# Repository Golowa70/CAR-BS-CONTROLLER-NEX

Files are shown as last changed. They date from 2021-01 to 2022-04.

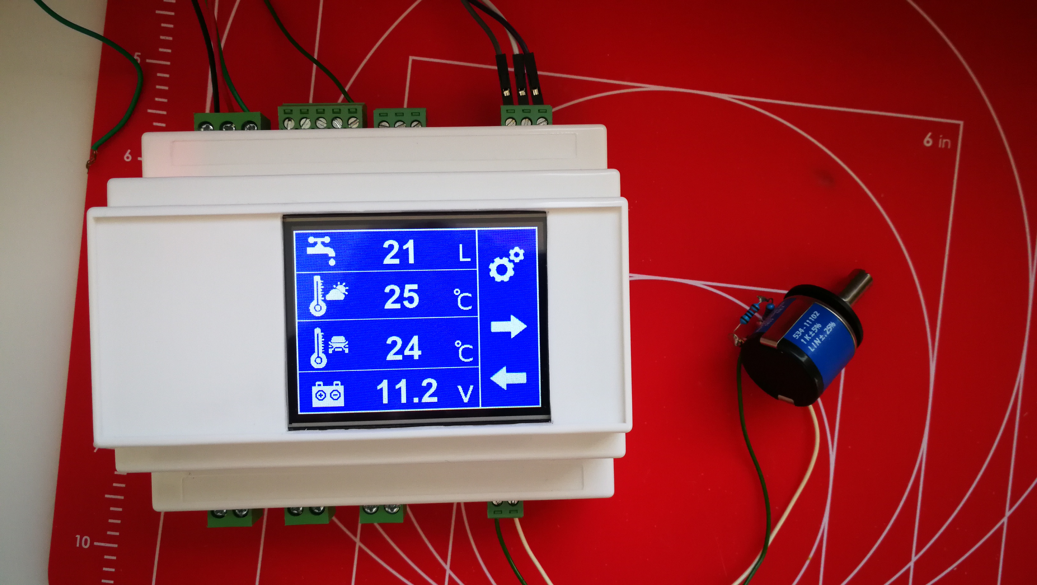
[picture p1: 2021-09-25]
Photo/IMG_20210619_180537.jpg

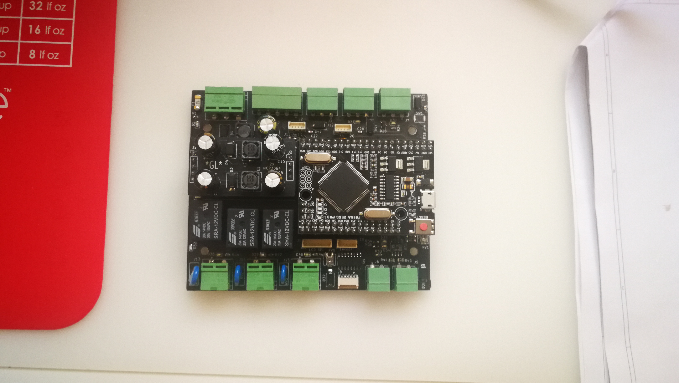
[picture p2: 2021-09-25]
Photo/IMG_20210616_192407.jpg

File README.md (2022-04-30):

# CAR-BS-CONTROLLER-NEX

Контроллер для дополнительного оборудования автомобиля на базе ардуино Mega  c сенсорным экраном Nextion. В качестве дополнительного оборудования установлен преобразователь напряжения 12/220в(1500ватт), холодильник, бак с водой (включая эл.насос, датчик количества воды и датчик приближения для активации насоса ). 

На данный момент реализованы следующие функции: 

- Автоматическое отключение преобразователя напряжения как по напряжению так и по времени.

- Управление водяным насосом для мойки рук с помощью датчика приближения и индикация количества воды в баке.

- Звуковое оповещение низкого уровня воды в баке.

- Индикация  количества воды, наружной и внутренней температуры, напряжения аккумулятора. 

- Передача данных на головное устройство (Андроид магнитола) по протоколу ModBus.

- Таймер на полное отключение контроллера.

- Диагностика питания сенсоров, шины 1wire, шины Pjon swbb

На данный момент контроллер установлен в автомобиле Hyundai I800 и успешно используется.

Прошивка контроллера  по прежнему находится в стадии разработки и тестирования.

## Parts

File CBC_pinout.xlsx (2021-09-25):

Pin | Direction | Function | Description | Столбец5
D2 | OUT | BUZZER | выход ШИМ на пассивную пищалку для звуковой индикации
D3 | IN/OUT | PJON BUS | выход интерфейса PJON
D4 | IN/OUT | 1WIRE BUS | выход интерфейса 1WIRE
D5 | IN | WATER FLOW SENSOR | вход датчика (счетчика) протечки
D6 | OUT | RS485DE | выход управления направлением (приём/передача) RS485
D7 | OUT | 5V SENSORS ENABLE | выход управления питанием сенсоров +5в
D8 | OUT | ADM705 RESET | выход для сброса таймера ADM705
D9 | OUT | MAIN SUPPLY ENABLE | выход управления основным питанием 7.2в
D10 | IN | ONBOARD BUTTON | кнопка на плате
D13 | OUT | STATUS LED | светодиод состояния системы
D16 | UART2 TX | RS485 TX
D17 | UART2 RX | RS485 RX
D18 | UART1 TX | *LCD NEXTION TX | разъём J11
D19 | UART1 RX | *LCD NEXTION RX | разъём J11
D20 | I2C SDA | * | разъём J12
D21 | I2C SCL | * | разъём J12
D22 | OUT | WATER PUMP OUT | выход управления реле водяного насоса
D23 | OUT | LIGHT OUT | выход управления светом
D24 | OUT | CONVERTER OUT | выход управления конвертером 12/220
D31 | OUT | SPARE OUT 1 | резервный выход 1 разъём J8
D32 | OUT | SPARE OUT 2 | резервный выход 2 разъём J8
D33 | OUT | SPARE OUT 3 | резервный выход 3 разъём J8
D34 | OUT | SPARE OUT 4 | резервный выход 4 разъём J8
D35 | IN | ENCODER SW | вход энкодера (кнопка) разъём J10
D36 | IN | ENCODER DT | вход энкодера (данные) разъём J10
D37 | IN | ENCODER CLK | вход энкодера (сигнал синхронизации) разъём J10
D41 | IN | POWER OK FROM ADM705 | вход от компаратора входного напряжения
D42 | IN | SPARE INPUT 1 | резервный вход
D43 | OUT | LCD RST | выход сброса экрана разъём J9 | ST7920
D44 | OUT | LCD BLA | выход управления подсветкой экрана разъём J9
D51 |  | LCD RW (SPI MOSI) | аппаратный SPI линия данных разъём J9
D52 |  | LCD E (SPI CLK) | аппаратный SPI линия синхронизации разъём J9
D53 |  | LCD DI (SPI CS) | аппаратный SPI линия выбора слэйва разъём J9
A0 | IN | DOOR SWITCH
A1 | IN | PROXIMITY SENSOR/BUTTON
A2 | IN | IGNITION SWITCH
A3 | IN | WASHER WATER LEVEL
A4 | IN | SUPPLY VOLTAGE
A5 | IN | SENSORS VOLTAGE
A6 | IN | RESESTIVE SENSOR | 0-190 OHM

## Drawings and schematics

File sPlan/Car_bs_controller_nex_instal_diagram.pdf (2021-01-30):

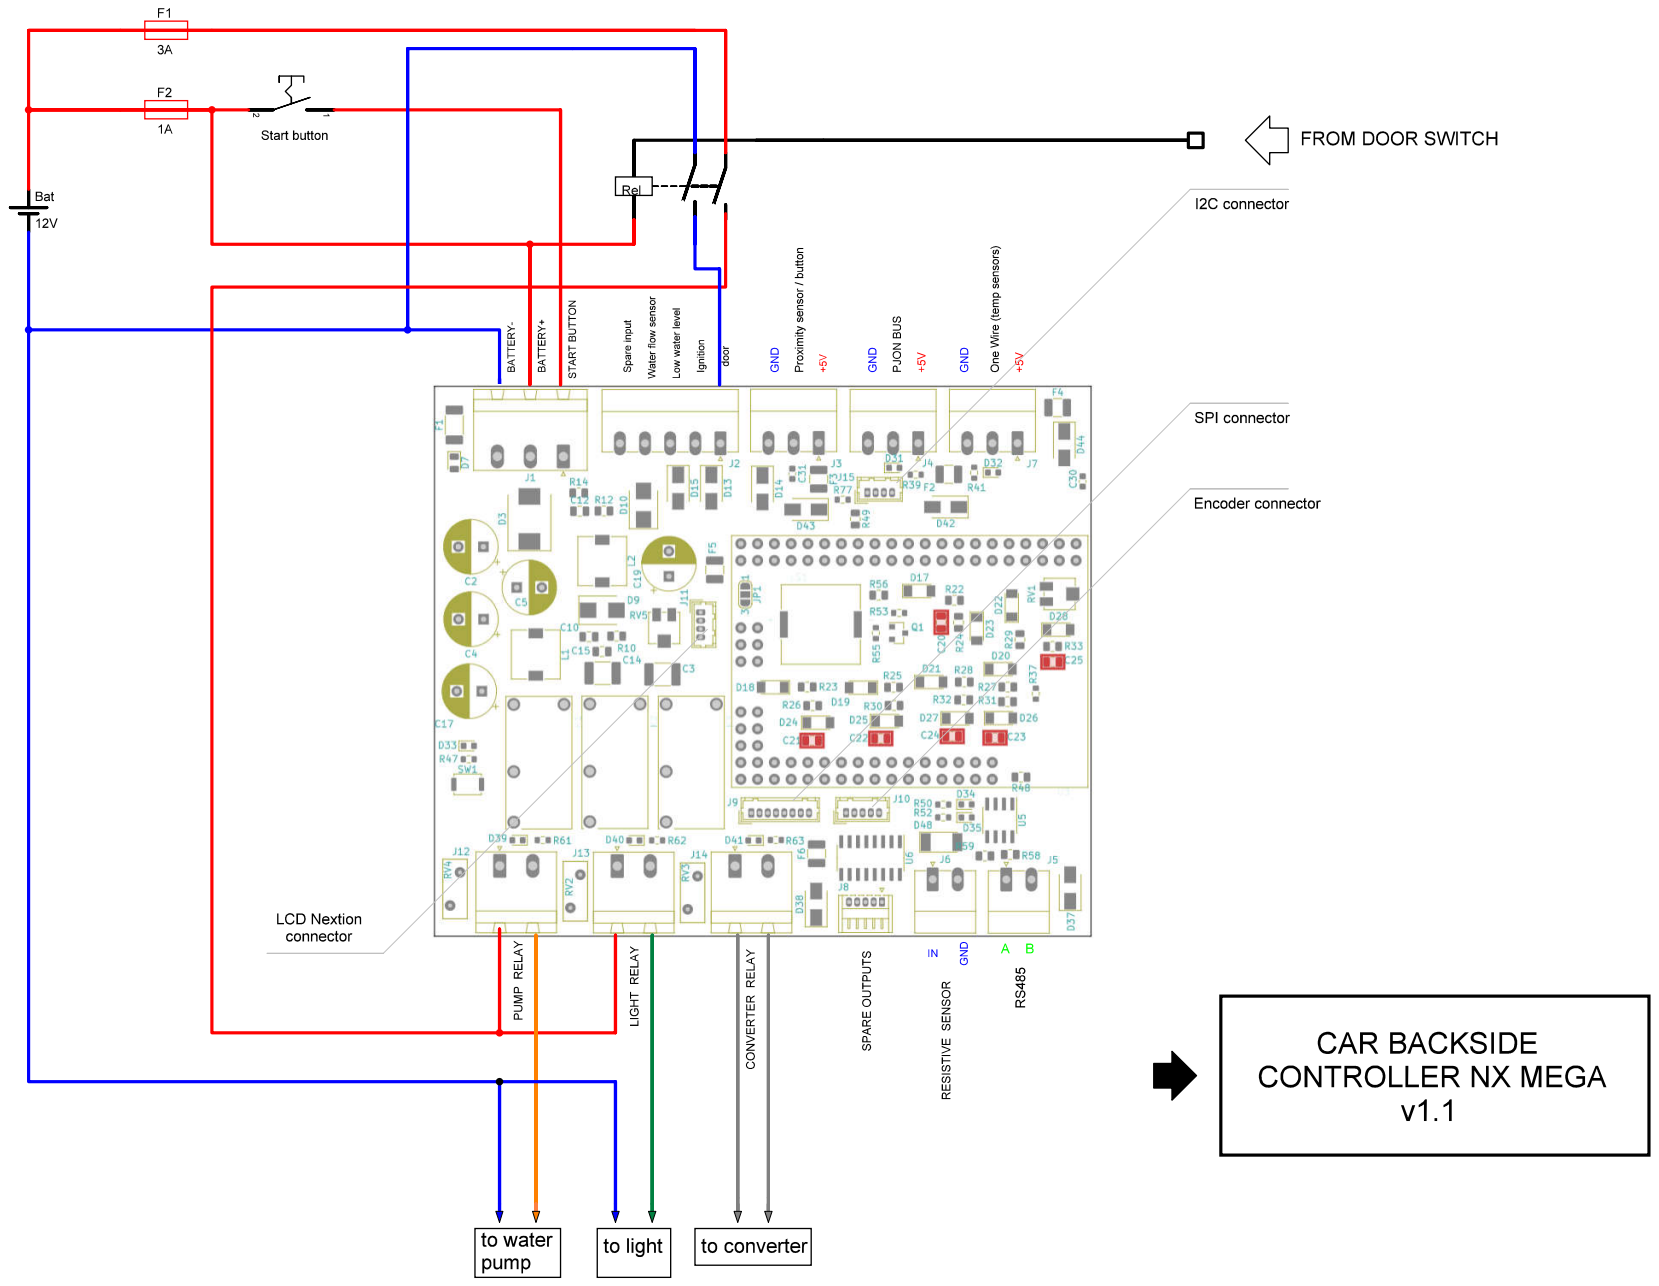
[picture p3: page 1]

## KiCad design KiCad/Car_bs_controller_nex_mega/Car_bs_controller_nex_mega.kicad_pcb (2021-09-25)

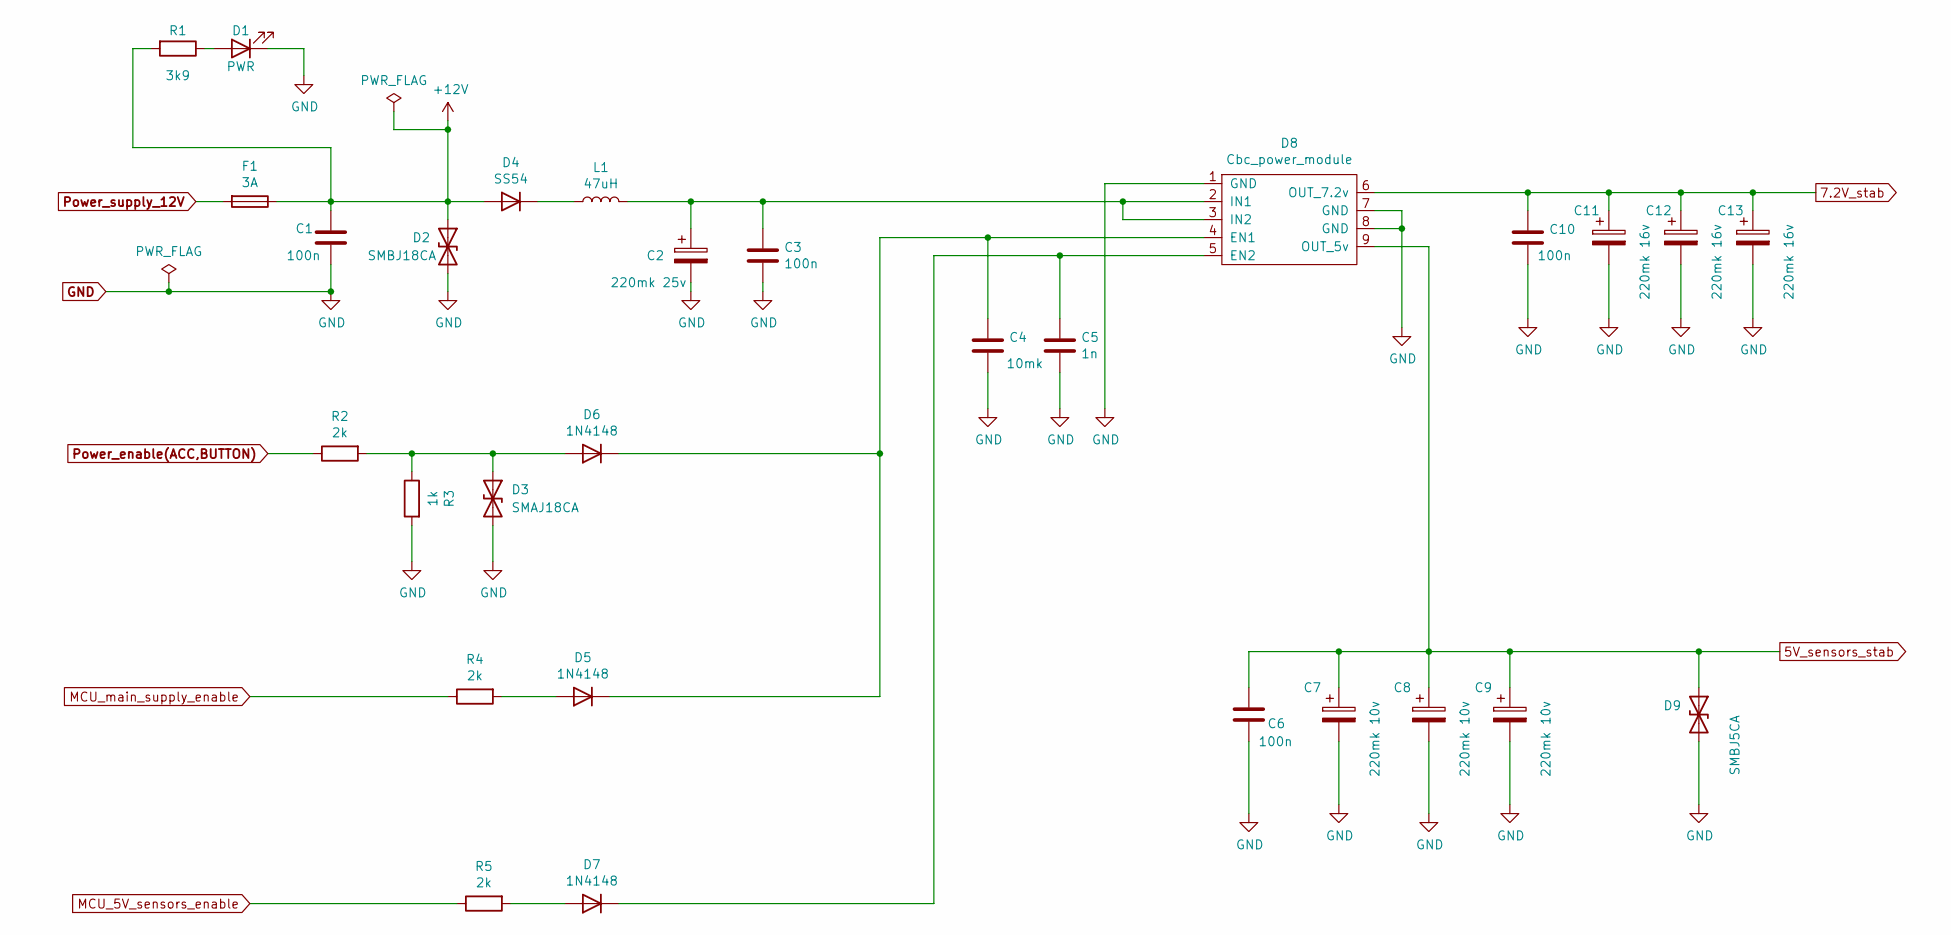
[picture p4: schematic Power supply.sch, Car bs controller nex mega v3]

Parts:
C1, C3, C6, C10: 100n; C_0805_2012Metric
C2: 220mk 25v; CP_Radial_D8.0mm_P3.80mm
C4: 10mk; C_1210_3225Metric_Pad1.33x2.70mm_HandSolder
C5: 1n; C_0805_2012Metric
C7, C8, C9: 220mk 10v; CP_Radial_D6.3mm_P2.50mm
C11, C12, C13: 220mk 16v; CP_Radial_D6.3mm_P2.50mm
D1: PWR; LED_0805_2012Metric
D2: SMBJ18CA; D_SMB
D3: SMAJ18CA; D_SMA
D4: SS54; D_SMB
D5, D6, D7: 1N4148; D_MiniMELF
D8: Cbc_power_module
D9: SMBJ5CA; D_SMA
F1: 3A; Fuse_2010_5025Metric
L1: 47uH; L_7.3x7.3_H4.5
R1: 3k9; R_0603_1608Metric_Pad0.98x0.95mm_HandSolder
R2, R4, R5: 2k; R_0603_1608Metric_Pad0.98x0.95mm_HandSolder
R3: 1k; R_0603_1608Metric_Pad0.98x0.95mm_HandSolder

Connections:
5V_sensors_stab: C6.1, C7.1, C8.1, C9.1, D8.9 (OUT_5v), D9.1 (A1); also elsewhere on the board
7.2V_stab: C10.1, C11.1, C12.1, C13.1, D8.6 (OUT_7.2v); also elsewhere on the board
+12V: C1.1, D2.1 (A1), D4.2 (A), F1.1, R1.2; also elsewhere on the board
GND: C1.2, C2.2, C3.2, C4.2, C5.2, C6.2, C7.2, C8.2, C9.2, C10.2, C11.2, C12.2, C13.2, D1.1 (K), D2.2 (A2), D3.2 (A2), D8.1 (GND), D8.7 (GND), D8.8 (GND), D9.2 (A2), R3.2; also elsewhere on the board
MCU_5V_sensors_enable: R5.1; also elsewhere on the board
MCU_main_supply_enable: R4.1; also elsewhere on the board
unnamed: C2.1, C3.1, D8.2 (IN1), D8.3 (IN2), L1.2
unnamed: C4.1, D5.1 (K), D6.1 (K), D8.4 (EN1)
unnamed: C5.1, D7.1 (K), D8.5 (EN2)
unnamed: D1.2 (A), R1.1
unnamed: D3.1 (A1), D6.2 (A), R2.2, R3.1
unnamed: D4.1 (K), L1.1
unnamed: D5.2 (A), R4.2
unnamed: D7.2 (A), R5.2
Power_enable(ACC,BUTTON): R2.1; also elsewhere on the board
Power_supply_12V: F1.2; also elsewhere on the board

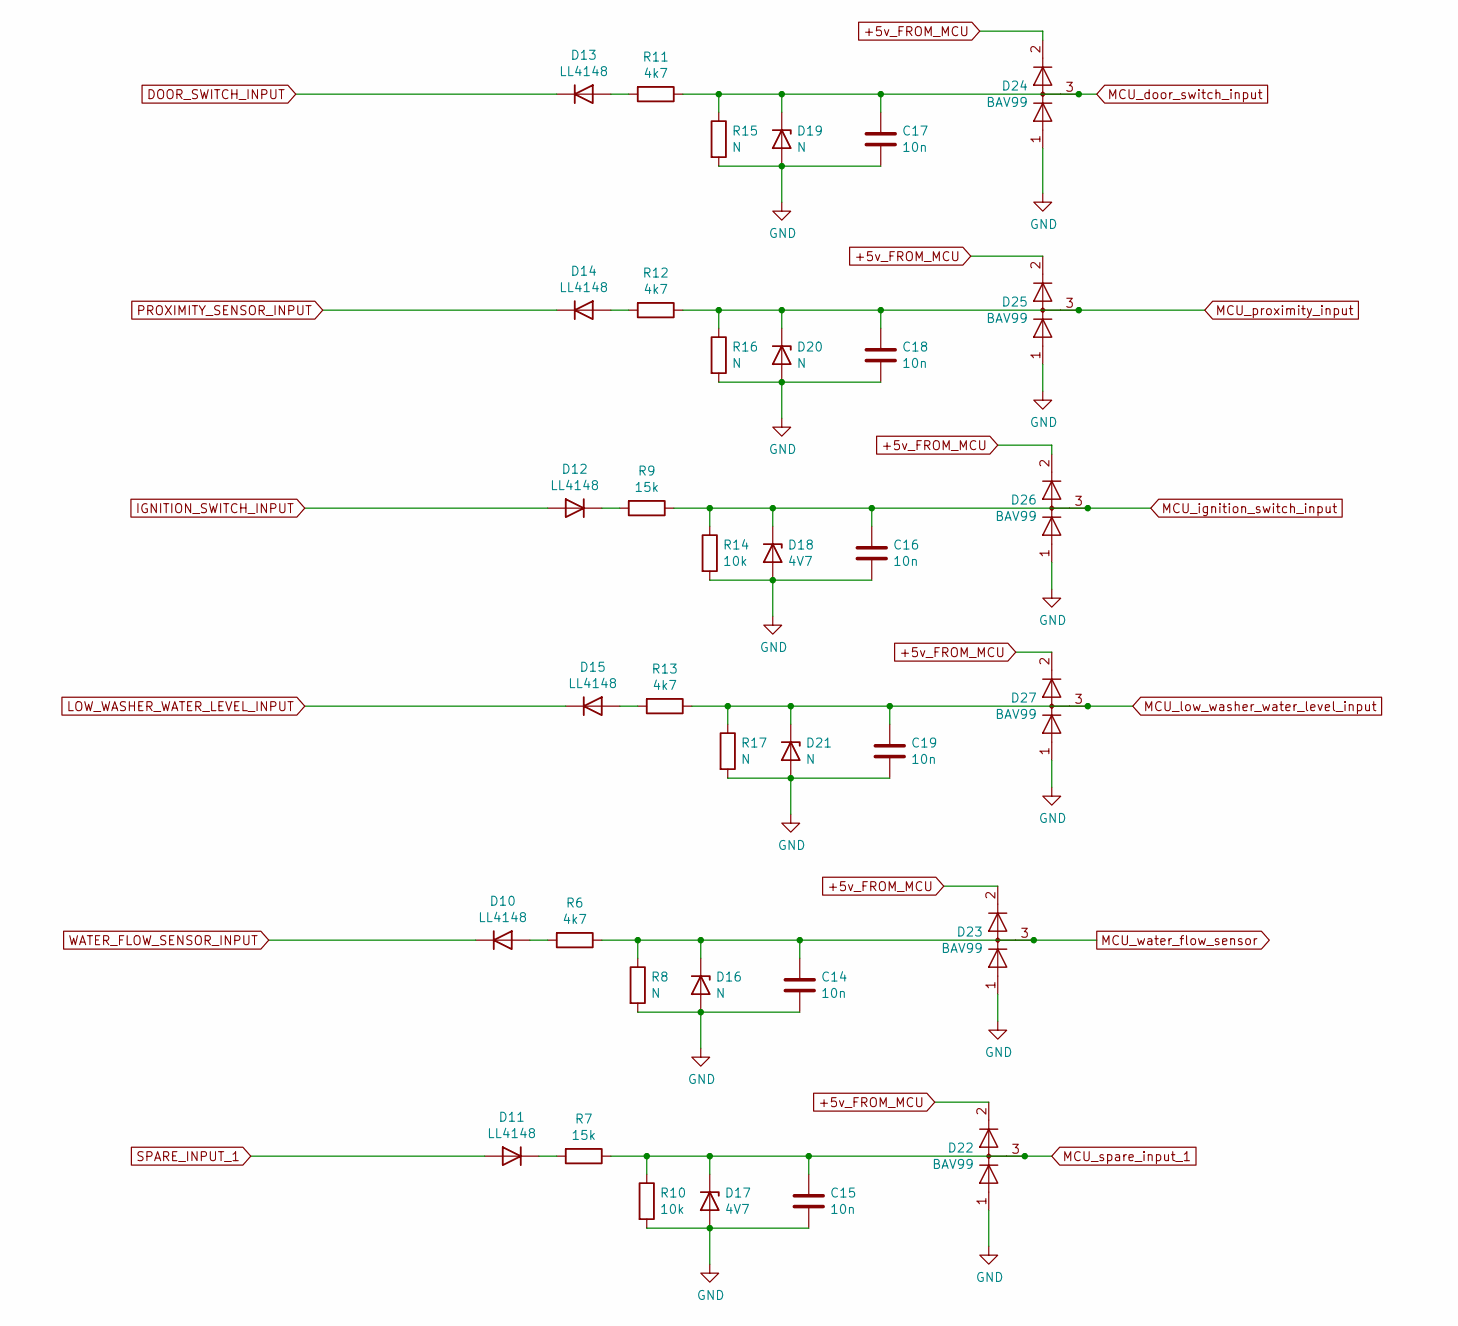
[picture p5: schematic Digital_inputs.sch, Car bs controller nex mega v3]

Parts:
C14, C15, C16, C17, C18, C19: 10n; C_0603_1608Metric_Pad1.08x0.95mm_HandSolder
D10, D11, D12, D13, D14, D15: LL4148; D_MiniMELF
D16, D19, D20, D21: N; D_MiniMELF
D17, D18: 4V7; D_MiniMELF
D22, D23, D24, D25, D26, D27: BAV99; SOT-23
R6, R11, R12, R13: 4k7; R_0603_1608Metric_Pad0.98x0.95mm_HandSolder
R7, R9: 15k; R_0603_1608Metric_Pad0.98x0.95mm_HandSolder
R8, R15, R16, R17: N; R_0603_1608Metric_Pad0.98x0.95mm_HandSolder
R10, R14: 10k; R_0603_1608Metric_Pad0.98x0.95mm_HandSolder

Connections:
+5v_FROM_MCU: D22.2 (A), D23.2 (A), D24.2 (A), D25.2 (A), D26.2 (A), D27.2 (A); also elsewhere on the board
DOOR_SWITCH_INPUT: D13.1 (K); also elsewhere on the board
GND: C14.2, C15.2, C16.2, C17.2, C18.2, C19.2, D16.2 (A), D17.2 (A), D18.2 (A), D19.2 (A), D20.2 (A), D21.2 (A), D22.1 (K), D23.1 (K), D24.1 (K), D25.1 (K), D26.1 (K), D27.1 (K), R8.2, R10.2, R14.2, R15.2, R16.2, R17.2; also elsewhere on the board
IGNITION_SWITCH_INPUT: D12.2 (A); also elsewhere on the board
LOW_WASHER_WATER_LEVEL_INPUT: D15.1 (K); also elsewhere on the board
MCU_door_switch_input: C17.1, D19.1 (K), D24.3 (K), R11.1, R15.1; also elsewhere on the board
MCU_ignition_switch_input: C16.1, D18.1 (K), D26.3 (K), R9.1, R14.1; also elsewhere on the board
MCU_low_washer_water_level_input: C19.1, D21.1 (K), D27.3 (K), R13.1, R17.1; also elsewhere on the board
MCU_proximity_input: C18.1, D20.1 (K), D25.3 (K), R12.1, R16.1; also elsewhere on the board
MCU_spare_input_1: C15.1, D17.1 (K), D22.3 (K), R7.1, R10.1; also elsewhere on the board
MCU_water_flow_sensor: C14.1, D16.1 (K), D23.3 (K), R6.1, R8.1; also elsewhere on the board
unnamed: D10.2 (A), R6.2
unnamed: D11.1 (K), R7.2
unnamed: D12.1 (K), R9.2
unnamed: D13.2 (A), R11.2
unnamed: D14.2 (A), R12.2
unnamed: D15.2 (A), R13.2
PROXIMITY_SENSOR_INPUT: D14.1 (K); also elsewhere on the board
SPARE_INPUT_1: D11.2 (A); also elsewhere on the board
WATER_FLOW_SENSOR_INPUT: D10.1 (K); also elsewhere on the board

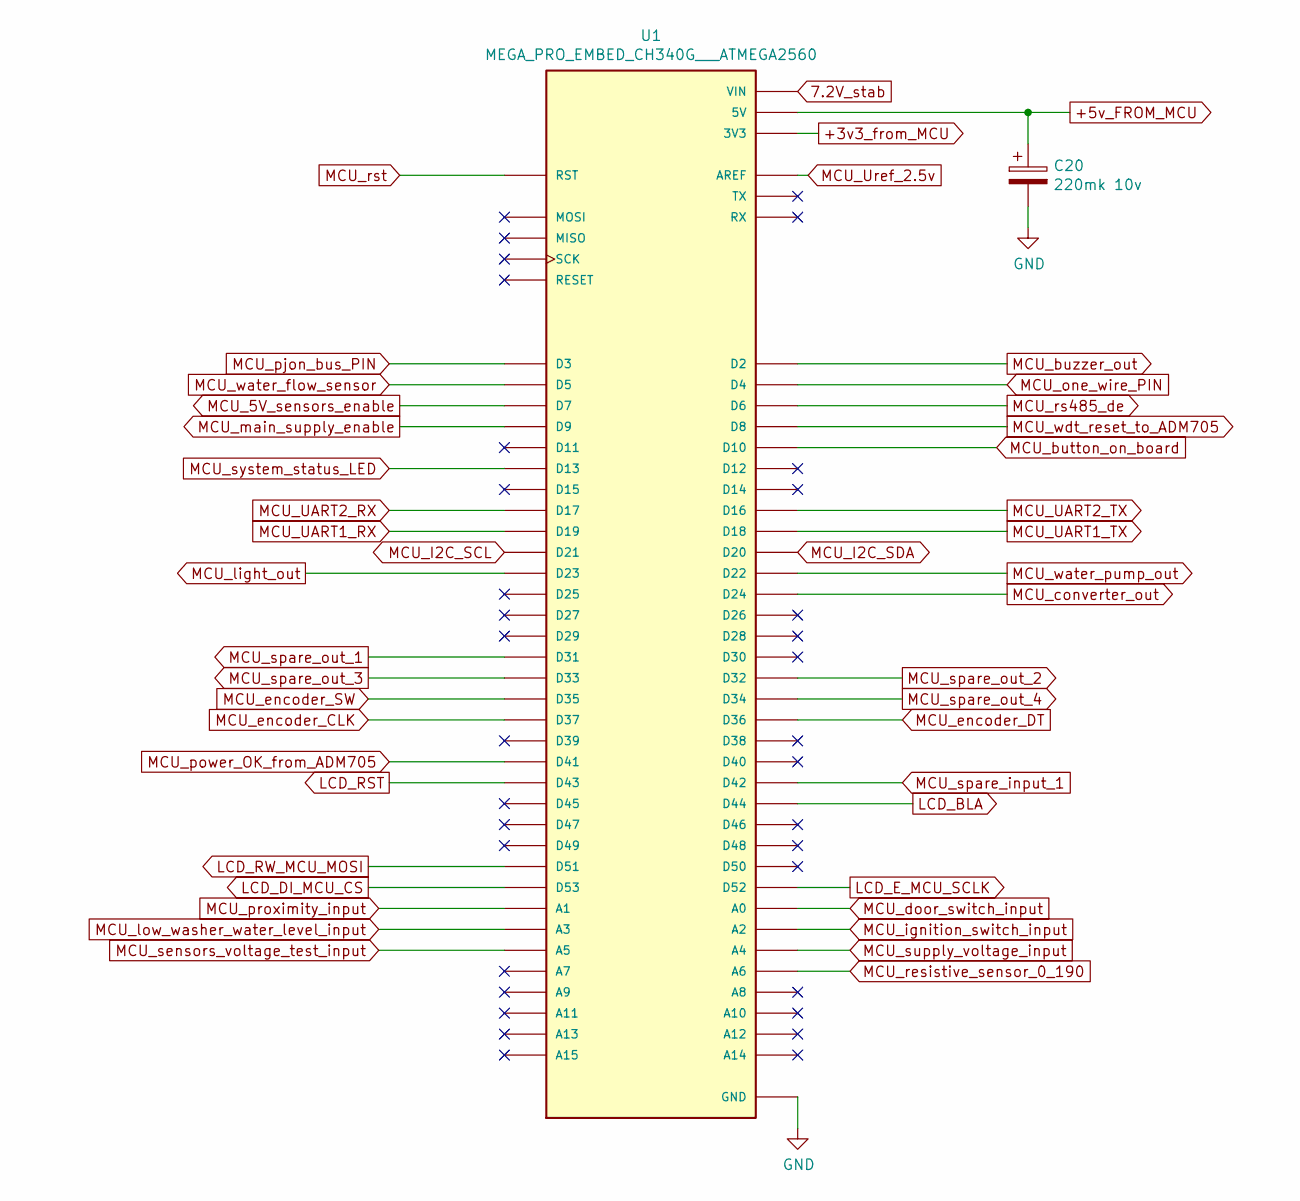
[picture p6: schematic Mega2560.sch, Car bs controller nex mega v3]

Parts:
C20: 220mk 10v; CP_Radial_D6.3mm_P2.50mm
U1: MEGA_PRO_EMBED_CH340G___ATMEGA2560; _ATMEGA2560; PARTREV 12/May/2017

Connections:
7.2V_stab: U1.VIN_1 (VIN); also elsewhere on the board
+3v3_from_MCU: U1.3V3_1 (3V3), U1.3V3_2 (3V3); also elsewhere on the board
+5v_FROM_MCU: C20.1, U1.5V_1 (5V); also elsewhere on the board
GND: C20.2, U1.GND_1 (GND), U1.GND_2 (GND), U1.GND_3 (GND); also elsewhere on the board
LCD_BLA: U1.D44; also elsewhere on the board
LCD_DI_MCU_CS: U1.D53; also elsewhere on the board
LCD_E_MCU_SCLK: U1.D52; also elsewhere on the board
LCD_RST: U1.D43; also elsewhere on the board
LCD_RW_MCU_MOSI: U1.D51; also elsewhere on the board
MCU_5V_sensors_enable: U1.D7; also elsewhere on the board
MCU_I2C_SCL: U1.D21; also elsewhere on the board
MCU_I2C_SDA: U1.D20; also elsewhere on the board
MCU_UART1_RX: U1.D19; also elsewhere on the board
MCU_UART1_TX: U1.D18; also elsewhere on the board
MCU_UART2_RX: U1.D17; also elsewhere on the board
MCU_UART2_TX: U1.D16; also elsewhere on the board
MCU_Uref_2.5v: U1.AREF; also elsewhere on the board
MCU_button_on_board: U1.D10; also elsewhere on the board
MCU_buzzer_out: U1.D2; also elsewhere on the board
MCU_converter_out: U1.D24; also elsewhere on the board
MCU_door_switch_input: U1.A0; also elsewhere on the board
MCU_encoder_CLK: U1.D37; also elsewhere on the board
MCU_encoder_DT: U1.D36; also elsewhere on the board
MCU_encoder_SW: U1.D35; also elsewhere on the board
MCU_ignition_switch_input: U1.A2; also elsewhere on the board
MCU_light_out: U1.D23; also elsewhere on the board
MCU_low_washer_water_level_input: U1.A3; also elsewhere on the board
MCU_main_supply_enable: U1.D9; also elsewhere on the board
MCU_one_wire_PIN: U1.D4; also elsewhere on the board
MCU_pjon_bus_PIN: U1.D3; also elsewhere on the board
MCU_power_OK_from_ADM705: U1.D41; also elsewhere on the board
MCU_proximity_input: U1.A1; also elsewhere on the board
MCU_resistive_sensor_0_190: U1.A6; also elsewhere on the board
MCU_rs485_de: U1.D6; also elsewhere on the board
MCU_rst: U1.RST; also elsewhere on the board
MCU_sensors_voltage_test_input: U1.A5; also elsewhere on the board
MCU_spare_input_1: U1.D42; also elsewhere on the board
MCU_spare_out_1: U1.D31; also elsewhere on the board
MCU_spare_out_2: U1.D32; also elsewhere on the board
MCU_spare_out_3: U1.D33; also elsewhere on the board
MCU_spare_out_4: U1.D34; also elsewhere on the board
MCU_supply_voltage_input: U1.A4; also elsewhere on the board
MCU_system_status_LED: U1.D13; also elsewhere on the board
MCU_water_flow_sensor: U1.D5; also elsewhere on the board
MCU_water_pump_out: U1.D22; also elsewhere on the board
MCU_wdt_reset_to_ADM705: U1.D8; also elsewhere on the board

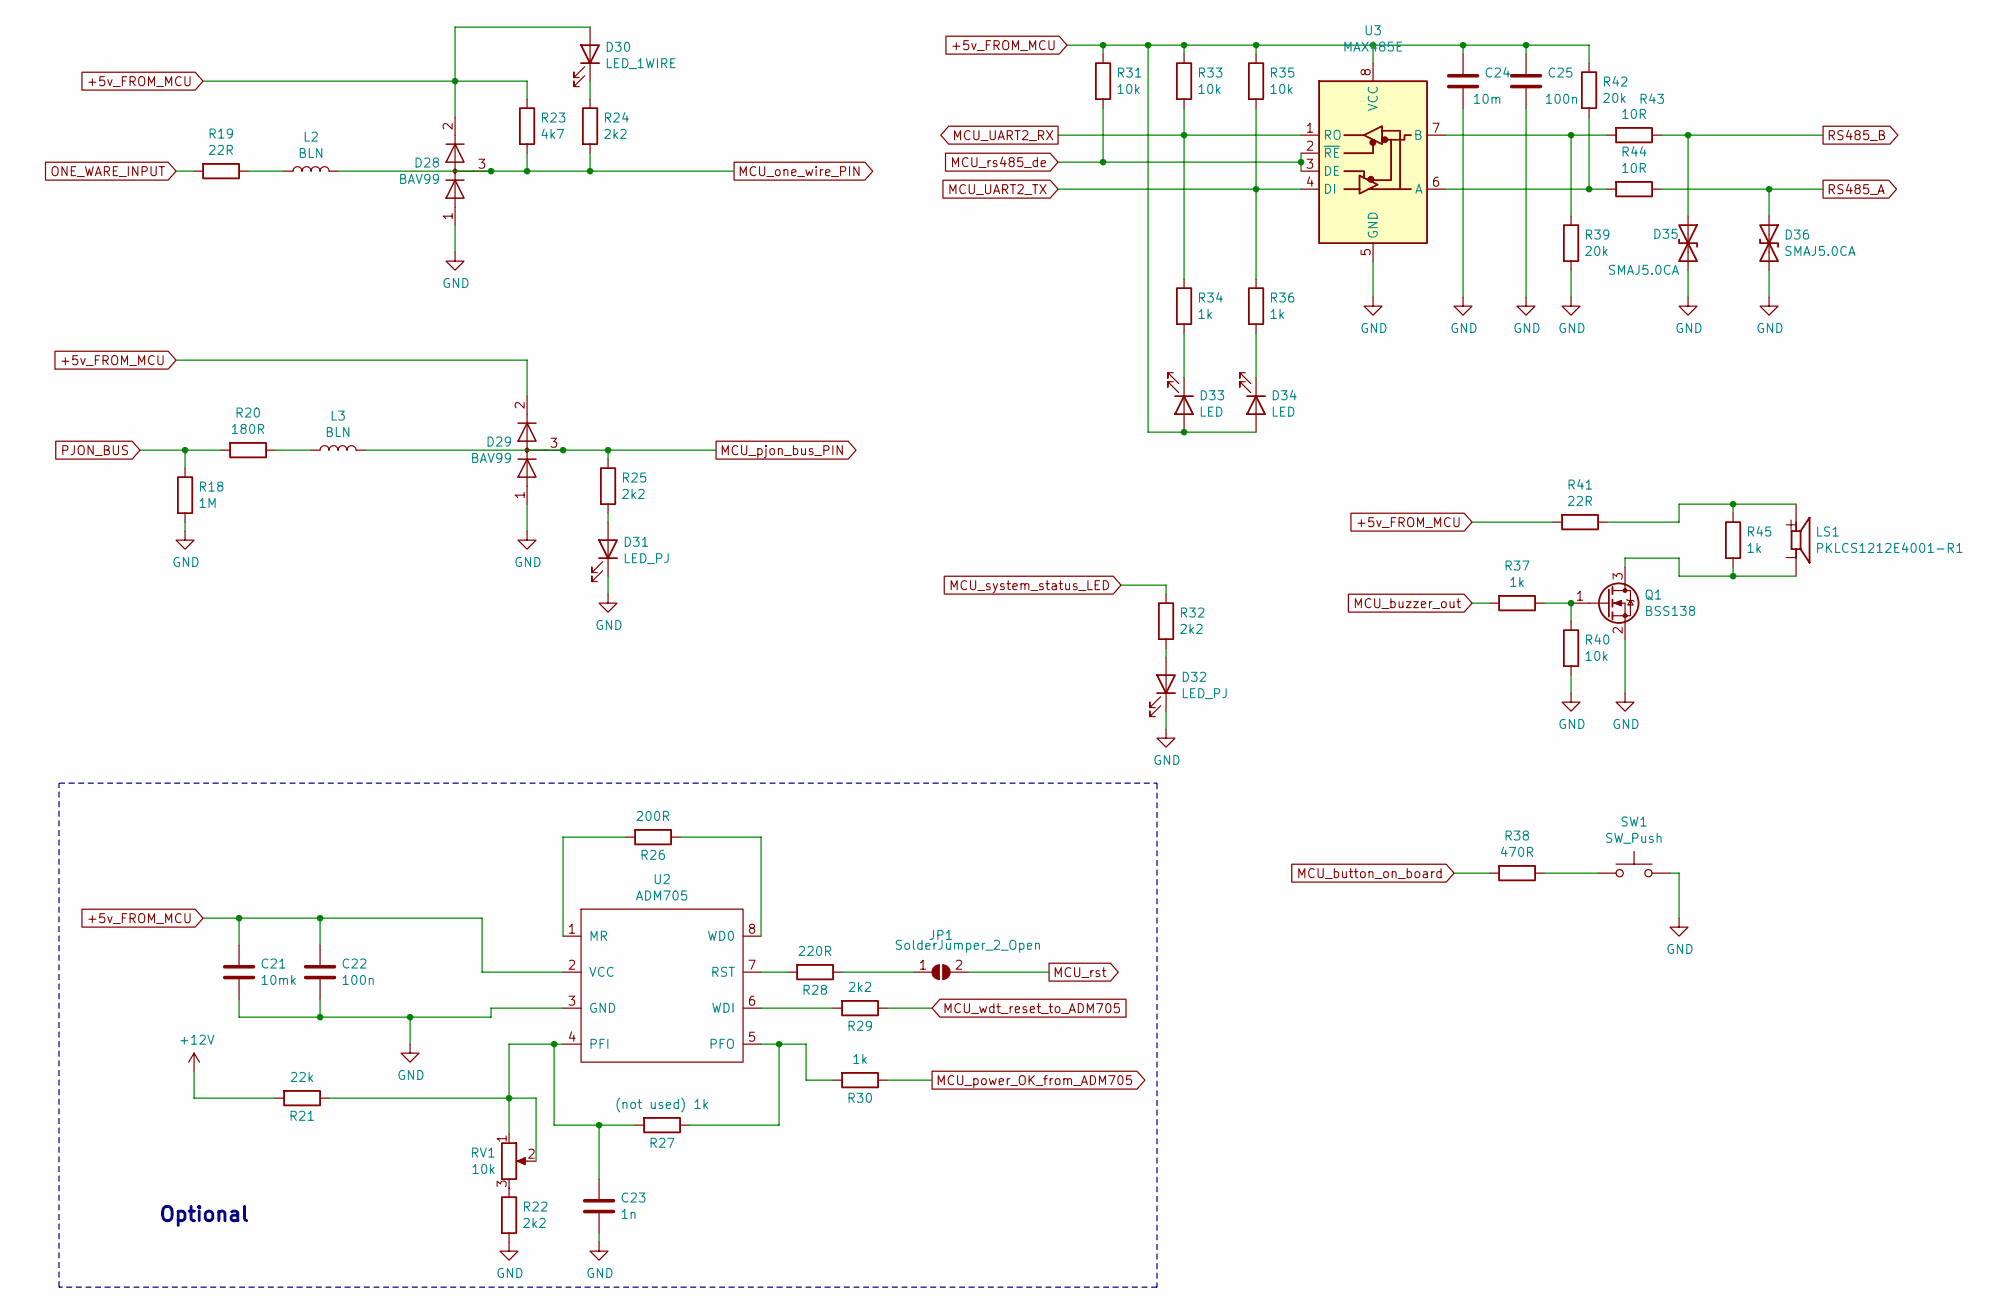
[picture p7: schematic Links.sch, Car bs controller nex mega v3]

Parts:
C21: 10mk; CP_EIA-7343-15_Kemet-W_Pad2.25x2.55mm_HandSolder
C22: 100n; R_0603_1608Metric
C23: 1n; R_0603_1608Metric_Pad0.98x0.95mm_HandSolder
C24: 10m; C_1210_3225Metric_Pad1.33x2.70mm_HandSolder
C25: 100n; C_0603_1608Metric_Pad1.08x0.95mm_HandSolder
D28, D29: BAV99; SOT-23
D30: LED_1WIRE; LED_0603_1608Metric
D31, D32: LED_PJ; LED_0603_1608Metric
D33, D34: LED; LED_0603_1608Metric
D35, D36: SMAJ5.0CA; D_SMA
JP1: SolderJumper_2_Open; SolderJumper-2_P1.3mm_Open_RoundedPad1.0x1.5mm
L2, L3: BLN; L_0805_2012Metric_Pad1.15x1.40mm_HandSolder
LS1: PKLCS1212E4001-R1; SPKR_PKLCS1212E4001-R1; PARTREV January 22, 2018
Q1: BSS138; SOT-23
R18: 1M; R_0805_2012Metric
R19, R41: 22R; R_0805_2012Metric
R20: 180R; R_0805_2012Metric
R21: 22k; R_0603_1608Metric_Pad0.98x0.95mm_HandSolder
R22, R29: 2k2; R_0603_1608Metric_Pad0.98x0.95mm_HandSolder
R23: 4k7; R_0603_1608Metric_Pad0.98x0.95mm_HandSolder
R24, R25, R32: 2k2; R_0603_1608Metric
R26: 200R; R_0603_1608Metric_Pad0.98x0.95mm_HandSolder
R27: (not used) 1k; R_0603_1608Metric_Pad0.98x0.95mm_HandSolder
R28: 220R; R_0603_1608Metric_Pad0.98x0.95mm_HandSolder
R30, R37: 1k; R_0603_1608Metric_Pad0.98x0.95mm_HandSolder
R31, R33, R35, R40: 10k; R_0603_1608Metric_Pad0.98x0.95mm_HandSolder
R34, R36: 1k; R_0603_1608Metric
R38: 470R; R_0603_1608Metric_Pad0.98x0.95mm_HandSolder
R39, R42: 20k; R_0603_1608Metric_Pad0.98x0.95mm_HandSolder
R43, R44: 10R; R_0805_2012Metric
R45: 1k; R_0805_2012Metric_Pad1.20x1.40mm_HandSolder
RV1: 10k; Potentiometer_Bourns_3314J_Vertical
SW1: SW_Push; SW_Push_SPST_NO_Alps_SKRK
U2: ADM705; SOIC-8_3.9x4.9mm_P1.27mm
U3: MAX485E; SOIC-8_3.9x4.9mm_P1.27mm

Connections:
+5v_FROM_MCU: C21.1, C22.1, C24.1, C25.1, D28.2 (A), D29.2 (A), D30.2 (A), D33.2 (A), D34.2 (A), R23.1, R31.1, R33.1, R35.1, R41.2, R42.1, U2.2 (VCC), U3.8 (VCC); also elsewhere on the board
+12V: R21.2; also elsewhere on the board
GND: C21.2, C22.2, C23.2, C24.2, C25.2, D28.1 (K), D29.1 (K), D31.1 (K), D32.1 (K), D35.2 (A2), D36.2 (A2), Q1.2 (S), R18.2, R22.2, R39.2, R40.2, SW1.2, U2.3 (GND), U3.5 (GND); also elsewhere on the board
MCU_UART2_RX: R33.2, R34.1, U3.1 (RO); also elsewhere on the board
MCU_UART2_TX: R35.2, R36.1, U3.4 (DI); also elsewhere on the board
MCU_button_on_board: R38.2; also elsewhere on the board
MCU_buzzer_out: R37.2; also elsewhere on the board
MCU_one_wire_PIN: D28.3 (K), L2.2, R23.2, R24.2; also elsewhere on the board
MCU_pjon_bus_PIN: D29.3 (K), L3.2, R25.1; also elsewhere on the board
MCU_power_OK_from_ADM705: R30.1; also elsewhere on the board
MCU_rs485_de: R31.2, U3.2 (~RE), U3.3 (DE); also elsewhere on the board
MCU_rst: JP1.2 (B); also elsewhere on the board
MCU_system_status_LED: R32.1; also elsewhere on the board
MCU_wdt_reset_to_ADM705: R29.1; also elsewhere on the board
unnamed: C23.1, R21.1, R27.2, RV1.1, RV1.2, U2.4 (PFI)
unnamed: D30.1 (K), R24.1
unnamed: D31.2 (A), R25.2
unnamed: D32.2 (A), R32.2
unnamed: D33.1 (K), R34.2
unnamed: D34.1 (K), R36.2
unnamed: JP1.1 (A), R28.1
unnamed: L2.1, R19.1
unnamed: L3.1, R20.1
unnamed: LS1.N, Q1.3 (D), R45.2
unnamed: LS1.P, R41.1, R45.1
unnamed: Q1.1 (G), R37.1, R40.1
unnamed: R22.1, RV1.3
unnamed: R26.1, U2.8 (WD0)
unnamed: R26.2, U2.1 (MR)
unnamed: R27.1, R30.2, U2.5 (PFO)
unnamed: R28.2, U2.7 (RST)
unnamed: R29.2, U2.6 (WDI)
unnamed: R38.1, SW1.1
unnamed: R39.1, R43.2, U3.7 (B)
unnamed: R42.2, R44.2, U3.6 (A)
ONE_WARE_INPUT: R19.2; also elsewhere on the board
PJON_BUS: R18.1, R20.2; also elsewhere on the board
RS485_A: D36.1 (A1), R44.1; also elsewhere on the board
RS485_B: D35.1 (A1), R43.1; also elsewhere on the board

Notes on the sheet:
Optional

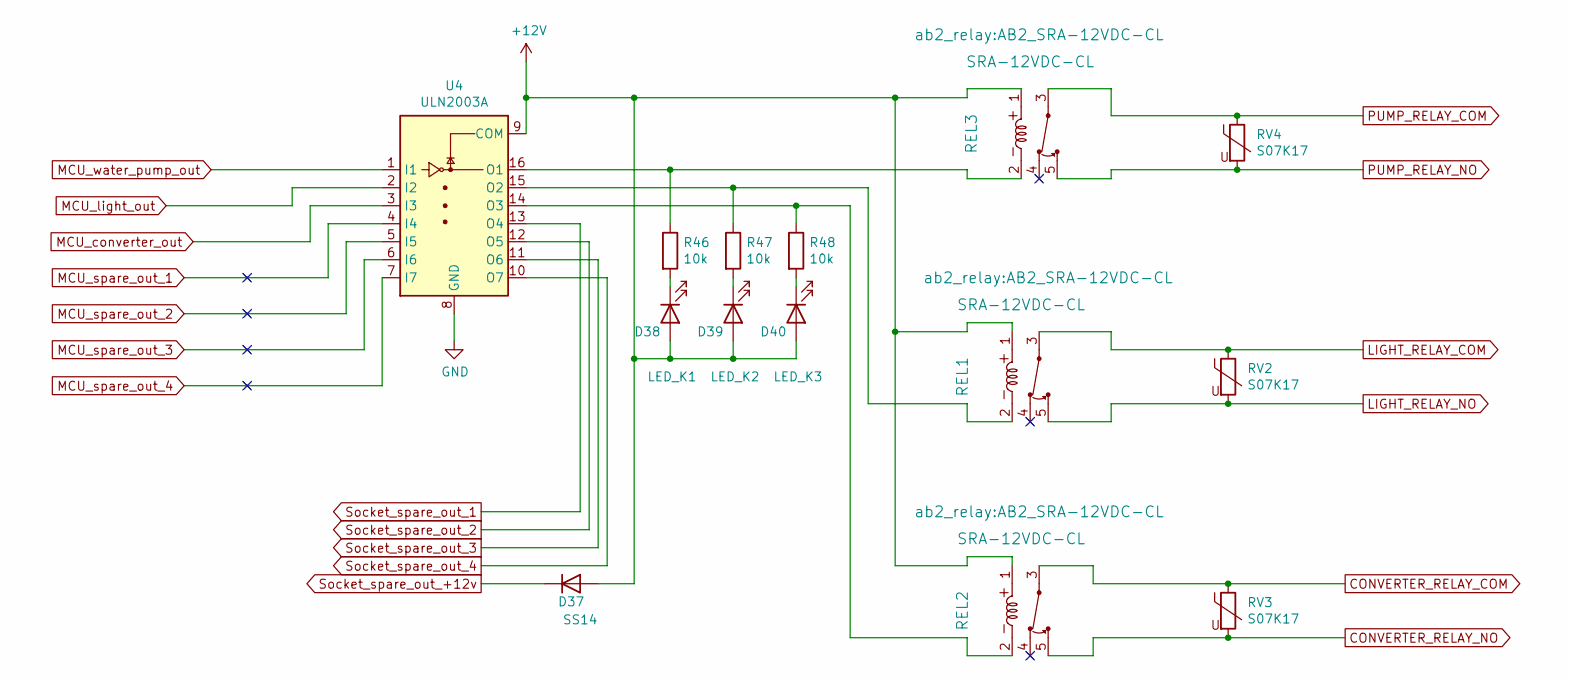
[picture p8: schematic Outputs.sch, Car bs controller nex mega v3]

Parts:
D37: SS14; D_SMA
D38: LED_K1; LED_0603_1608Metric
D39: LED_K2; LED_0603_1608Metric
D40: LED_K3; LED_0603_1608Metric
R46, R47, R48: 10k; R_0603_1608Metric
REL1, REL2, REL3: SRA-12VDC-CL; AB2_SRA-12VDC-CL
RV2, RV3, RV4: S07K17; RV_Disc_D9mm_W3.7mm_P5mm
U4: ULN2003A; SOIC-16_3.9x9.9mm_P1.27mm

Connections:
+12V: D37.1 (A), D38.2 (A), D39.2 (A), D40.2 (A), REL1.1, REL2.1, REL3.1, U4.9 (COM); also elsewhere on the board
CONVERTER_RELAY_COM: REL2.3, RV3.1; also elsewhere on the board
CONVERTER_RELAY_NO: REL2.5, RV3.2; also elsewhere on the board
GND: U4.8 (GND); also elsewhere on the board
LIGHT_RELAY_COM: REL1.3, RV2.1; also elsewhere on the board
LIGHT_RELAY_NO: REL1.5, RV2.2; also elsewhere on the board
MCU_converter_out: U4.3 (I3); also elsewhere on the board
MCU_light_out: U4.2 (I2); also elsewhere on the board
MCU_spare_out_1: U4.4 (I4); also elsewhere on the board
MCU_spare_out_2: U4.5 (I5); also elsewhere on the board
MCU_spare_out_3: U4.6 (I6); also elsewhere on the board
MCU_spare_out_4: U4.7 (I7); also elsewhere on the board
MCU_water_pump_out: U4.1 (I1); also elsewhere on the board
unnamed: D38.1 (K), R46.2
unnamed: D39.1 (K), R47.2
unnamed: D40.1 (K), R48.2
unnamed: R46.1, REL3.2, U4.16 (O1)
unnamed: R47.1, REL1.2, U4.15 (O2)
unnamed: R48.1, REL2.2, U4.14 (O3)
PUMP_RELAY_COM: REL3.3, RV4.1; also elsewhere on the board
PUMP_RELAY_NO: REL3.5, RV4.2; also elsewhere on the board
Socket_spare_out_1: U4.13 (O4); also elsewhere on the board
Socket_spare_out_2: U4.12 (O5); also elsewhere on the board
Socket_spare_out_3: U4.11 (O6); also elsewhere on the board
Socket_spare_out_4: U4.10 (O7); also elsewhere on the board
Socket_spare_out_+12v: D37.2 (K); also elsewhere on the board

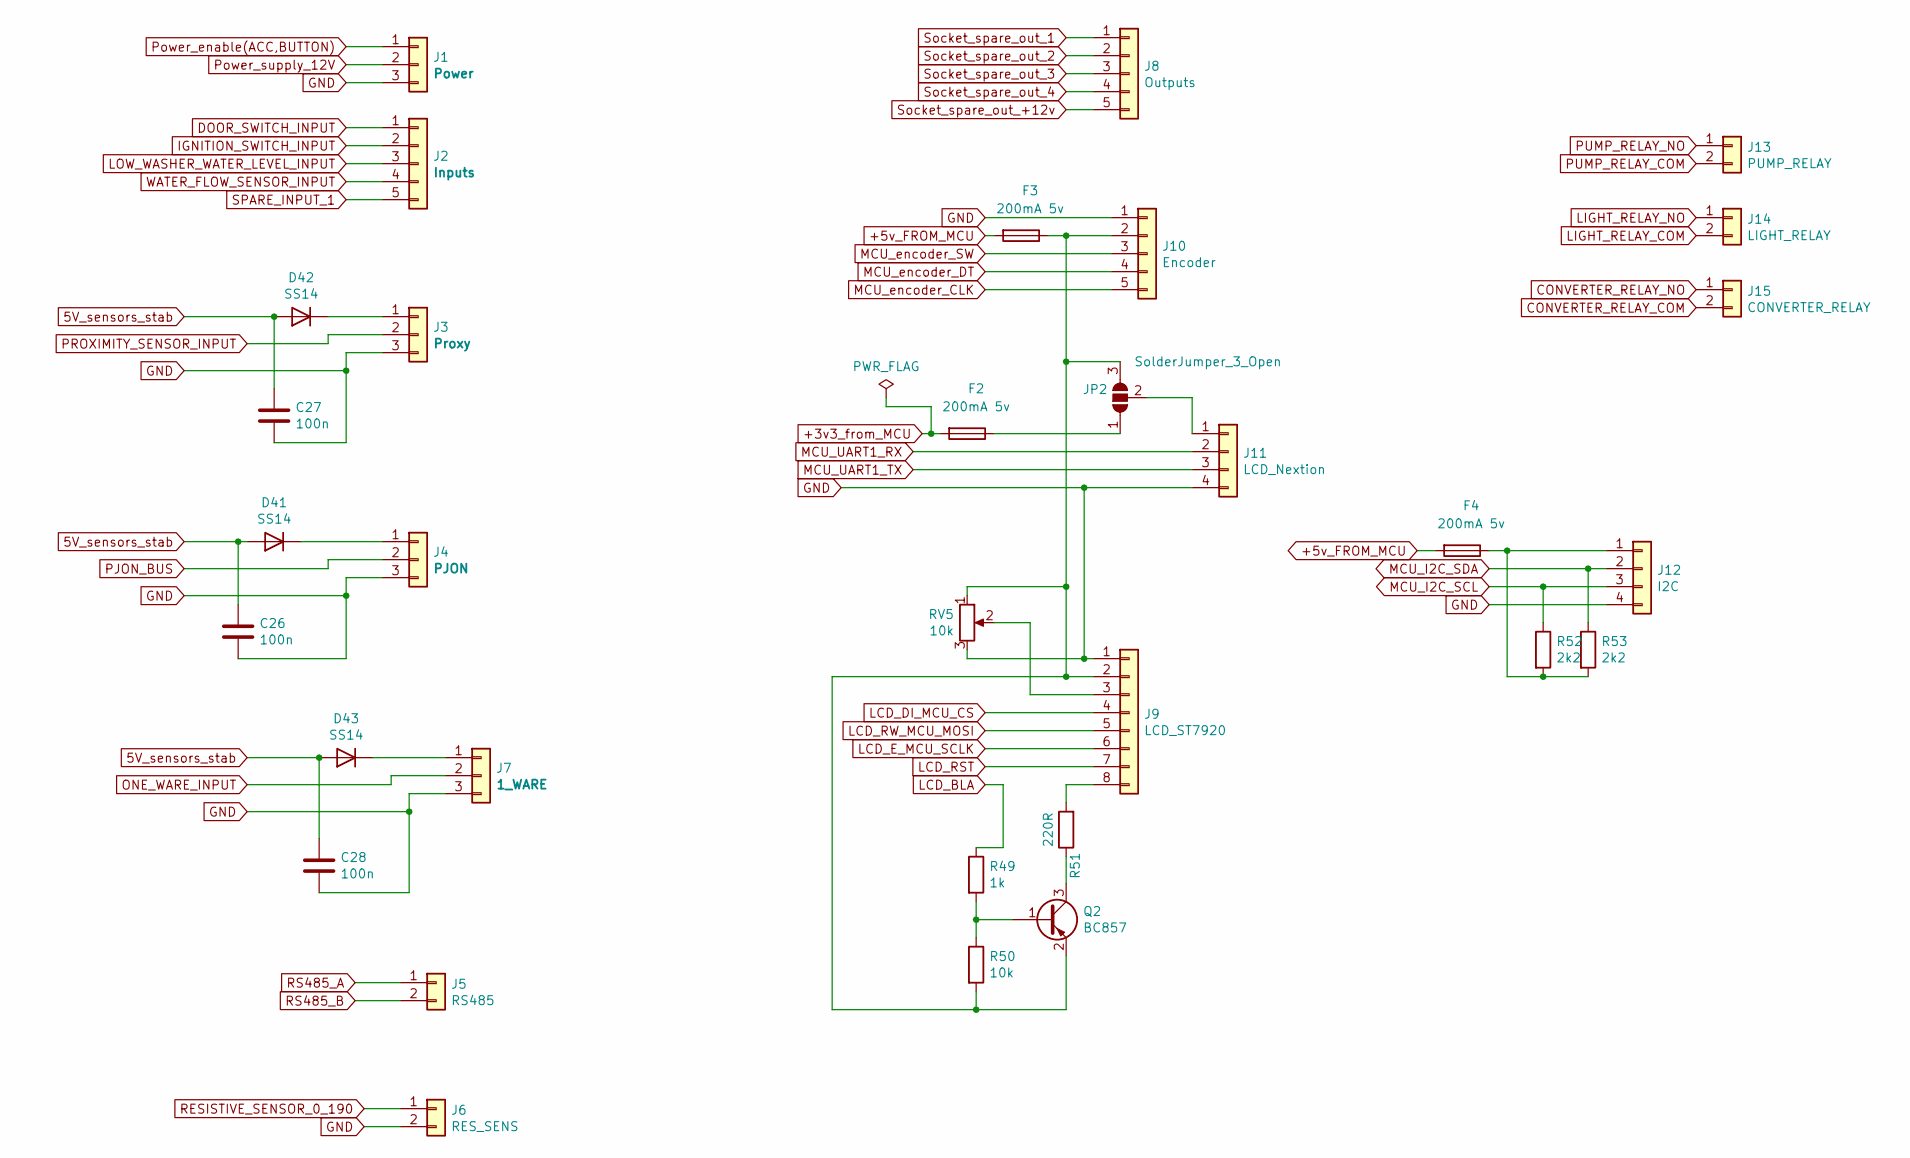
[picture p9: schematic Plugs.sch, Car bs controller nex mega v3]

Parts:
C26, C27, C28: 100n; C_0603_1608Metric
D41, D42, D43: SS14; D_SMA
F2, F3, F4: 200mA 5v; Fuse_1206_3216Metric_Pad1.42x1.75mm_HandSolder
J1: Power; PhoenixContact_MSTBA_2,5_3-G_1x03_P5.00mm_Horizontal
J2: Inputs; PhoenixContact_MC_1,5_5-G-3.81_1x05_P3.81mm_Horizontal
J3: Proxy; PhoenixContact_MC_1,5_3-G-3.81_1x03_P3.81mm_Horizontal
J4: PJON; PhoenixContact_MC_1,5_3-G-3.81_1x03_P3.81mm_Horizontal
J5: RS485; PhoenixContact_MC_1,5_2-G-3.81_1x02_P3.81mm_Horizontal
J6: RES_SENS; PhoenixContact_MC_1,5_2-G-3.81_1x02_P3.81mm_Horizontal
J7: 1_WARE; PhoenixContact_MC_1,5_3-G-3.81_1x03_P3.81mm_Horizontal
J8: Outputs; Hirose_DF13-05P-1.25DS_1x05_P1.25mm_Horizontal
J9: LCD_ST7920; Hirose_DF13-08P-1.25DSA_1x08_P1.25mm_Vertical
J10: Encoder; Hirose_DF13-05P-1.25DSA_1x05_P1.25mm_Vertical
J11: LCD_Nextion; Hirose_DF13-04P-1.25DSA_1x04_P1.25mm_Vertical
J12: I2C; Hirose_DF13-04P-1.25DSA_1x04_P1.25mm_Vertical
J13: PUMP_RELAY; PhoenixContact_MSTBA_2,5_2-G_1x02_P5.00mm_Horizontal
J14: LIGHT_RELAY; PhoenixContact_MSTBA_2,5_2-G_1x02_P5.00mm_Horizontal
J15: CONVERTER_RELAY; PhoenixContact_MSTBA_2,5_2-G_1x02_P5.00mm_Horizontal
JP2: SolderJumper_3_Open; SolderJumper-3_P1.3mm_Open_RoundedPad1.0x1.5mm_NumberLabels
Q2: BC857; SOT-23
R49: 1k; R_0603_1608Metric_Pad0.98x0.95mm_HandSolder
R50: 10k; R_0603_1608Metric_Pad0.98x0.95mm_HandSolder
R51: 220R; R_0805_2012Metric
R52, R53: 2k2; R_0603_1608Metric
RV5: 10k; Potentiometer_Bourns_3314J_Vertical

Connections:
5V_sensors_stab: C26.1, C27.1, C28.1, D41.1 (A), D42.1 (A), D43.1 (A); also elsewhere on the board
+3v3_from_MCU: F2.2; also elsewhere on the board
+5v_FROM_MCU: F3.2, F4.2; also elsewhere on the board
CONVERTER_RELAY_COM: J15.2; also elsewhere on the board
CONVERTER_RELAY_NO: J15.1; also elsewhere on the board
DOOR_SWITCH_INPUT: J2.1; also elsewhere on the board
GND: C26.2, C27.2, C28.2, J1.3, J3.3, J4.3, J6.2, J7.3, J9.1, J10.1, J11.4, J12.4, RV5.3; also elsewhere on the board
IGNITION_SWITCH_INPUT: J2.2; also elsewhere on the board
LCD_BLA: R49.1; also elsewhere on the board
LCD_DI_MCU_CS: J9.4; also elsewhere on the board
LCD_E_MCU_SCLK: J9.6; also elsewhere on the board
LCD_RST: J9.7; also elsewhere on the board
LCD_RW_MCU_MOSI: J9.5; also elsewhere on the board
LIGHT_RELAY_COM: J14.2; also elsewhere on the board
LIGHT_RELAY_NO: J14.1; also elsewhere on the board
LOW_WASHER_WATER_LEVEL_INPUT: J2.3; also elsewhere on the board
MCU_I2C_SCL: J12.3, R52.1; also elsewhere on the board
MCU_I2C_SDA: J12.2, R53.1; also elsewhere on the board
MCU_UART1_RX: J11.2; also elsewhere on the board
MCU_UART1_TX: J11.3; also elsewhere on the board
MCU_encoder_CLK: J10.5; also elsewhere on the board
MCU_encoder_DT: J10.4; also elsewhere on the board
MCU_encoder_SW: J10.3; also elsewhere on the board
unnamed: D41.2 (K), J4.1
unnamed: D42.2 (K), J3.1
unnamed: D43.2 (K), J7.1
unnamed: F2.1, JP2.1 (A)
unnamed: F3.1, J9.2, J10.2, JP2.3 (B), Q2.2 (E), R50.2, RV5.1
unnamed: F4.1, J12.1, R52.2, R53.2
unnamed: J9.3, RV5.2
unnamed: J9.8, R51.2
unnamed: J11.1, JP2.2 (C)
unnamed: Q2.1 (B), R49.2, R50.1
unnamed: Q2.3 (C), R51.1
ONE_WARE_INPUT: J7.2; also elsewhere on the board
PJON_BUS: J4.2; also elsewhere on the board
PROXIMITY_SENSOR_INPUT: J3.2; also elsewhere on the board
PUMP_RELAY_COM: J13.2; also elsewhere on the board
PUMP_RELAY_NO: J13.1; also elsewhere on the board
Power_enable(ACC,BUTTON): J1.1; also elsewhere on the board
Power_supply_12V: J1.2; also elsewhere on the board
RESISTIVE_SENSOR_0_190: J6.1; also elsewhere on the board
RS485_A: J5.1; also elsewhere on the board
RS485_B: J5.2; also elsewhere on the board
SPARE_INPUT_1: J2.5; also elsewhere on the board
Socket_spare_out_1: J8.1; also elsewhere on the board
Socket_spare_out_2: J8.2; also elsewhere on the board
Socket_spare_out_3: J8.3; also elsewhere on the board
Socket_spare_out_4: J8.4; also elsewhere on the board
Socket_spare_out_+12v: J8.5; also elsewhere on the board
WATER_FLOW_SENSOR_INPUT: J2.4; also elsewhere on the board

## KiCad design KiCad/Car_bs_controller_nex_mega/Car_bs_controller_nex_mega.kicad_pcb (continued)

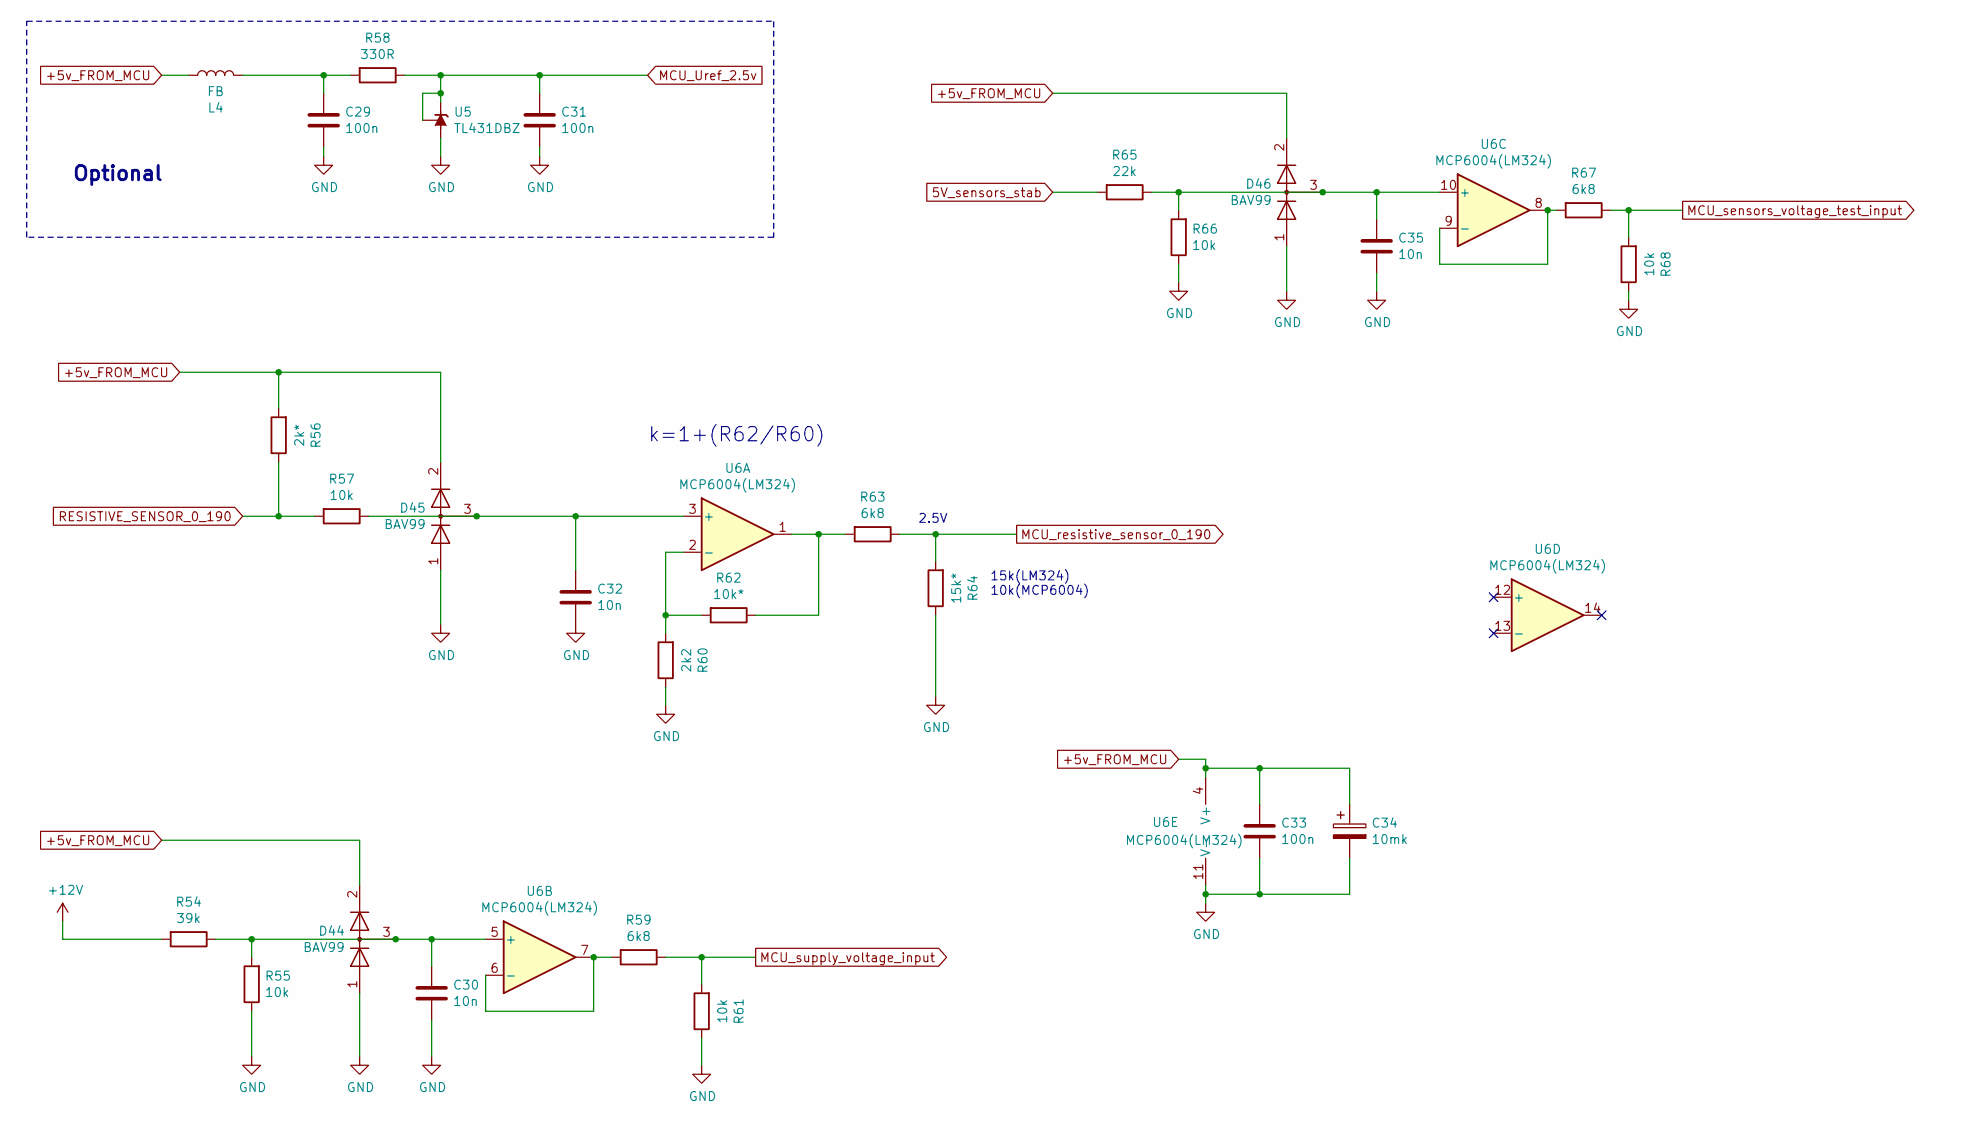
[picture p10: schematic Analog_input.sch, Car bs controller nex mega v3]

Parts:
C29, C31, C33: 100n; R_0603_1608Metric
C30, C32, C35: 10n; R_0603_1608Metric
C34: 10mk; CP_EIA-6032-15_Kemet-U
D44, D45, D46: BAV99; SOT-23
L4: FB; L_1206_3216Metric_Pad1.42x1.75mm_HandSolder
R54: 39k; R_0603_1608Metric_Pad0.98x0.95mm_HandSolder
R55, R57, R61, R66, R68: 10k; R_0603_1608Metric_Pad0.98x0.95mm_HandSolder
R56: 2k*; R_0805_2012Metric
R58: 330R; R_0805_2012Metric
R59, R63, R67: 6k8; R_0603_1608Metric_Pad0.98x0.95mm_HandSolder
R60: 2k2; R_0603_1608Metric_Pad0.98x0.95mm_HandSolder
R62: 10k*; R_0603_1608Metric_Pad0.98x0.95mm_HandSolder
R64: 15k*; R_0603_1608Metric_Pad0.98x0.95mm_HandSolder
R65: 22k; R_0603_1608Metric_Pad0.98x0.95mm_HandSolder
U5: TL431DBZ; SOT-23
U6: MCP6004(LM324); SOIC-14_3.9x8.7mm_P1.27mm

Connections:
5V_sensors_stab: R65.2; also elsewhere on the board
+5v_FROM_MCU: C33.1, C34.1, D44.2 (A), D45.2 (A), D46.2 (A), L4.1, R56.2, U6.4 (V+); also elsewhere on the board
+12V: R54.2; also elsewhere on the board
GND: C29.2, C30.2, C31.2, C32.2, C33.2, C34.2, C35.2, D44.1 (K), D45.1 (K), D46.1 (K), R55.1, R60.1, R61.1, R64.1, R66.1, R68.1, U5.3 (A), U6.11 (V-); also elsewhere on the board
MCU_Uref_2.5v: C31.1, R58.1, U5.1 (K), U5.2 (REF); also elsewhere on the board
MCU_resistive_sensor_0_190: R63.1, R64.2; also elsewhere on the board
MCU_sensors_voltage_test_input: R67.1, R68.2; also elsewhere on the board
MCU_supply_voltage_input: R59.1, R61.2; also elsewhere on the board
unnamed: C29.1, L4.2, R58.2
unnamed: C30.1, D44.3 (K), R54.1, R55.2, U6.5 (+)
unnamed: C32.1, D45.3 (K), R57.1, U6.3 (+)
unnamed: C35.1, D46.3 (K), R65.1, R66.2, U6.10 (+)
unnamed: R59.2, U6.6 (-), U6.7
unnamed: R60.2, R62.2, U6.2 (-)
unnamed: R62.1, R63.2, U6.1
unnamed: R67.2, U6.8, U6.9 (-)
RESISTIVE_SENSOR_0_190: R56.1, R57.2; also elsewhere on the board

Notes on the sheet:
k=1+(R62/R60)
15k(LM324) 10k(MCP6004)
2.5V
Optional

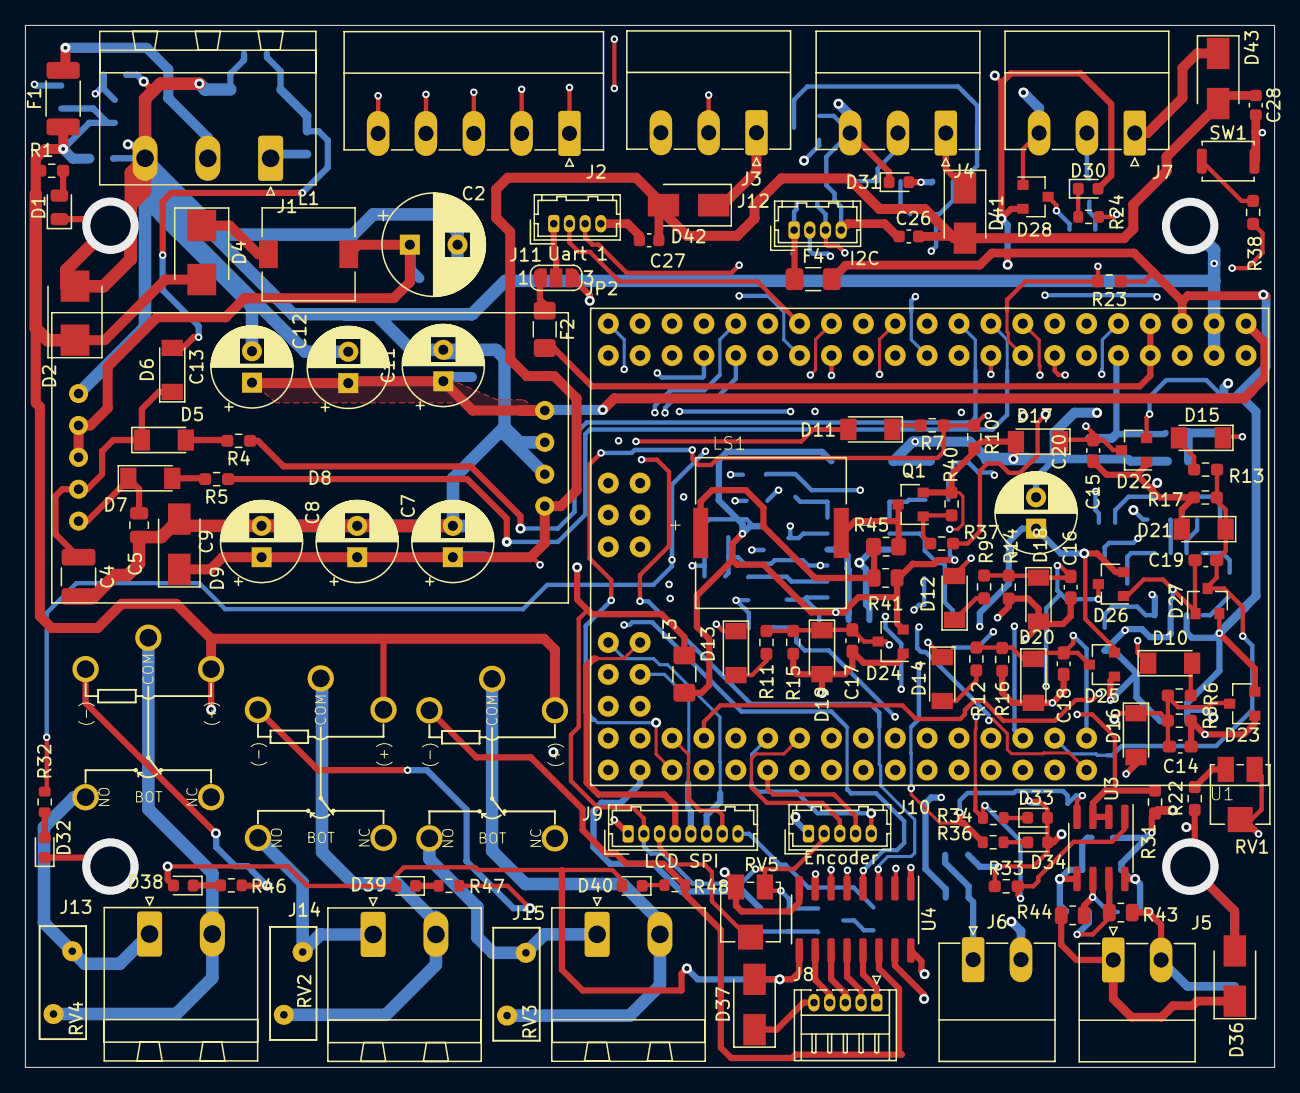
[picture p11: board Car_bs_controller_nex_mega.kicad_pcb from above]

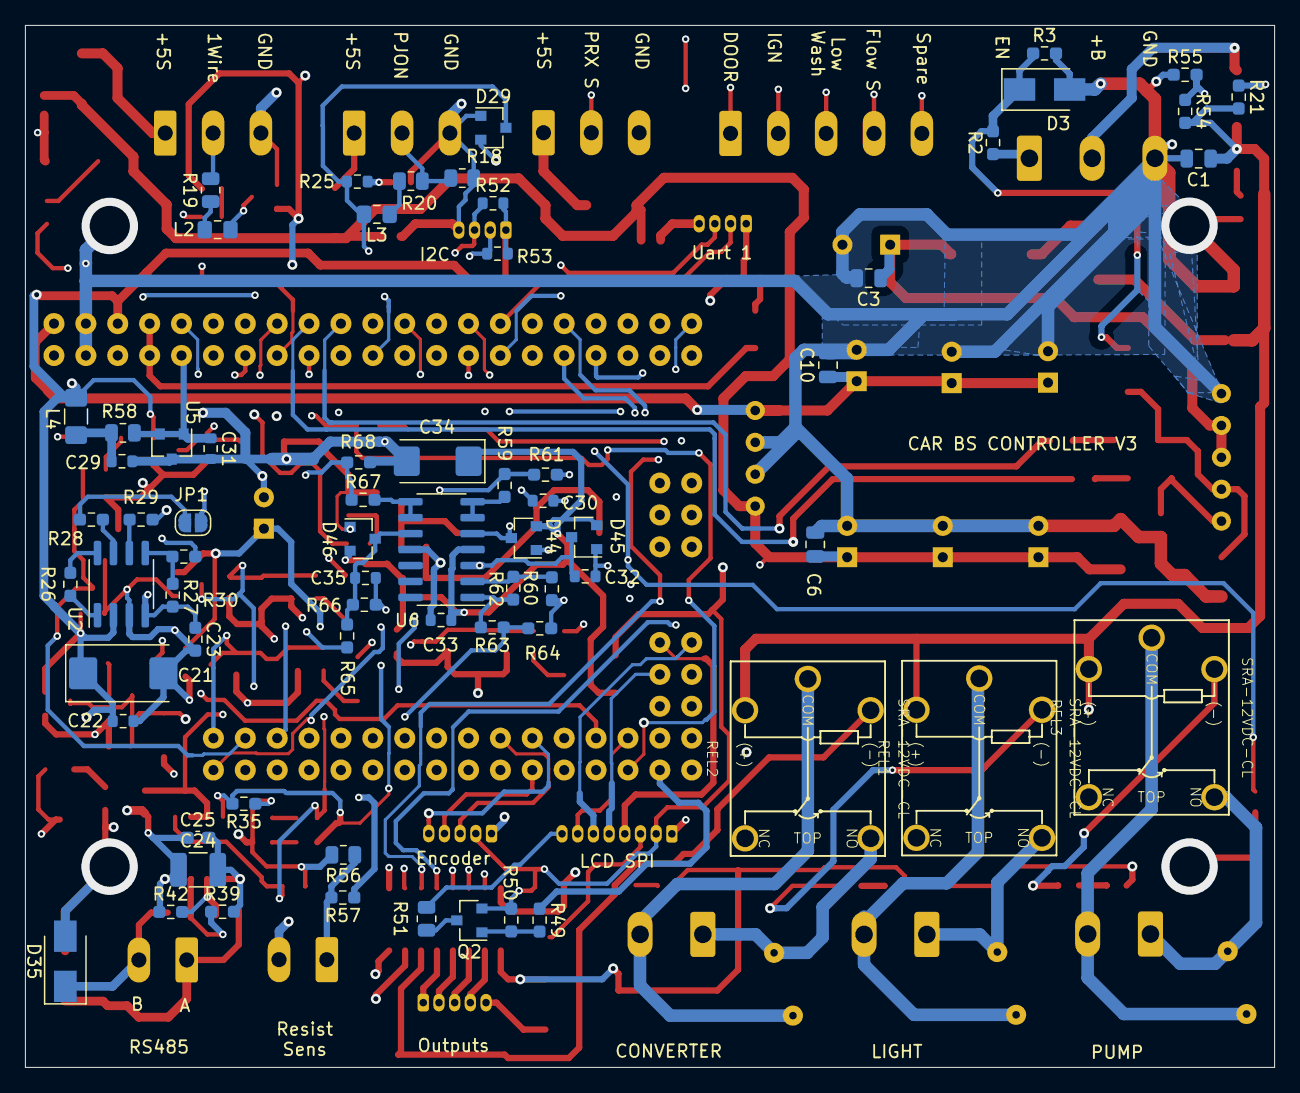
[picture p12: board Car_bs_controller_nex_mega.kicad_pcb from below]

Board: 4 copper layers, 99.5 x 83.0 mm, 192 parts (68 on the bottom side), 132 nets.

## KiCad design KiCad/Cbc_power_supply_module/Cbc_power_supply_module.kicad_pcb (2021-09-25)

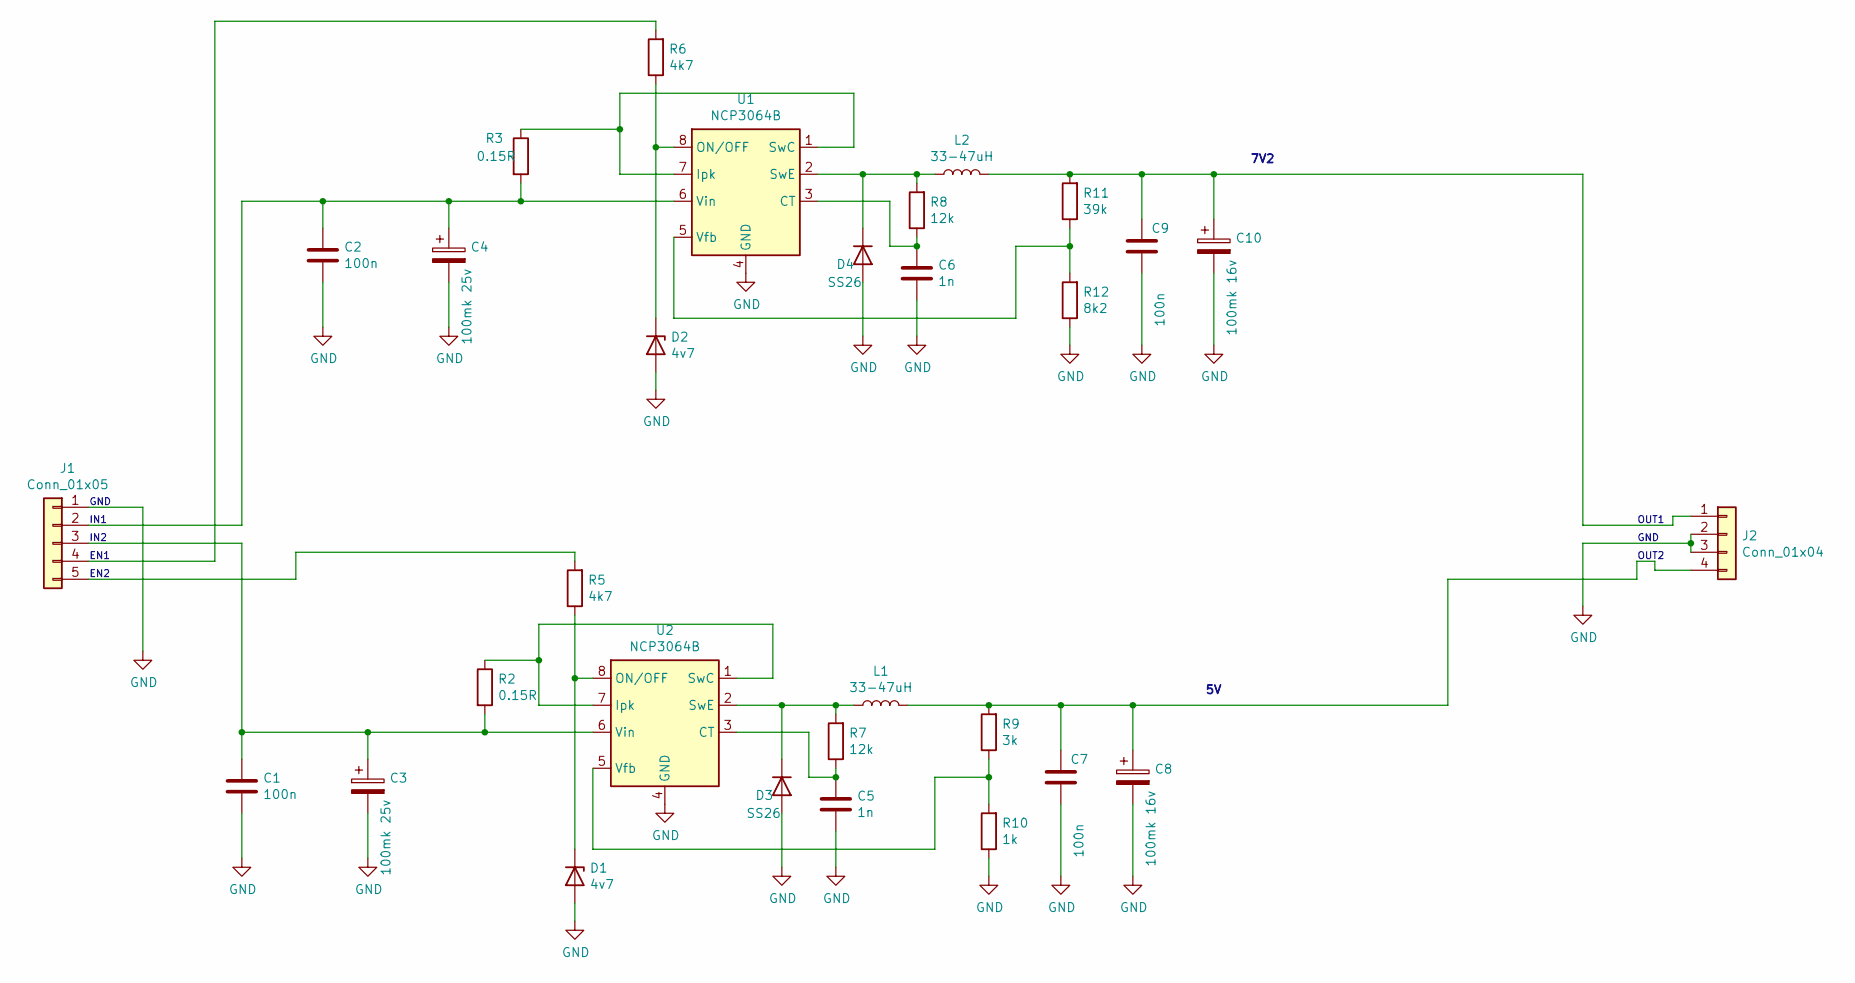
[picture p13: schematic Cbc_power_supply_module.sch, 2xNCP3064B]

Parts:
C1, C2, C7, C9: 100n; C_0805_2012Metric_Pad1.18x1.45mm_HandSolder
C3, C4: 100mk 25v; CP_Radial_D8.0mm_P3.80mm
C5, C6: 1n; C_0805_2012Metric_Pad1.18x1.45mm_HandSolder
C8, C10: 100mk 16v; CP_Radial_D8.0mm_P3.80mm
D1, D2: 4v7; D_MiniMELF
D3, D4: SS26; D_SMB
J1: Conn_01x05; PinHeader_1x05_P2.54mm_Vertical
J2: Conn_01x04; PinHeader_1x04_P2.54mm_Vertical
L1, L2: 33-47uH; L_7.3x7.3_H4.5
R2, R3: 0.15R; R_1210_3225Metric_Pad1.30x2.65mm_HandSolder
R5, R6: 4k7; R_0603_1608Metric_Pad0.98x0.95mm_HandSolder
R7, R8: 12k; R_0805_2012Metric_Pad1.20x1.40mm_HandSolder
R9: 3k; R_0805_2012Metric_Pad1.20x1.40mm_HandSolder
R10: 1k; R_0805_2012Metric_Pad1.20x1.40mm_HandSolder
R11: 39k; R_0805_2012Metric_Pad1.20x1.40mm_HandSolder
R12: 8k2; R_0805_2012Metric_Pad1.20x1.40mm_HandSolder
U1, U2: NCP3064B; SOIC-8_3.9x4.9mm_P1.27mm

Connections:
GND: C1.2, C2.2, C3.2, C4.2, C5.2, C6.2, C7.2, C8.2, C9.2, C10.2, D1.2 (A), D2.2 (A), D3.2 (A), D4.2 (A), J1.1, J2.2, J2.3, R10.1, R12.1, U1.4 (GND), U2.4 (GND)
unnamed: C1.1, C3.1, J1.3, R2.2, U2.6 (Vin)
unnamed: C2.1, C4.1, J1.2, R3.2, U1.6 (Vin)
unnamed: C5.1, R7.1, U2.3 (CT)
unnamed: C6.1, R8.1, U1.3 (CT)
unnamed: C7.1, C8.1, J2.4, L1.2, R9.2
unnamed: C9.1, C10.1, J2.1, L2.2, R11.2
unnamed: D1.1 (K), R5.1, U2.8 (ON/OFF)
unnamed: D2.1 (K), R6.1, U1.8 (ON/OFF)
unnamed: D3.1 (K), L1.1, R7.2, U2.2 (SwE)
unnamed: D4.1 (K), L2.1, R8.2, U1.2 (SwE)
unnamed: J1.4, R6.2
unnamed: J1.5, R5.2
unnamed: R2.1, U2.1 (SwC), U2.7 (Ipk)
unnamed: R3.1, U1.1 (SwC), U1.7 (Ipk)
unnamed: R9.1, R10.2, U2.5 (Vfb)
unnamed: R11.1, R12.2, U1.5 (Vfb)

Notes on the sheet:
7V2
GND
IN1
OUT1
EN1
IN2
OUT2
EN2

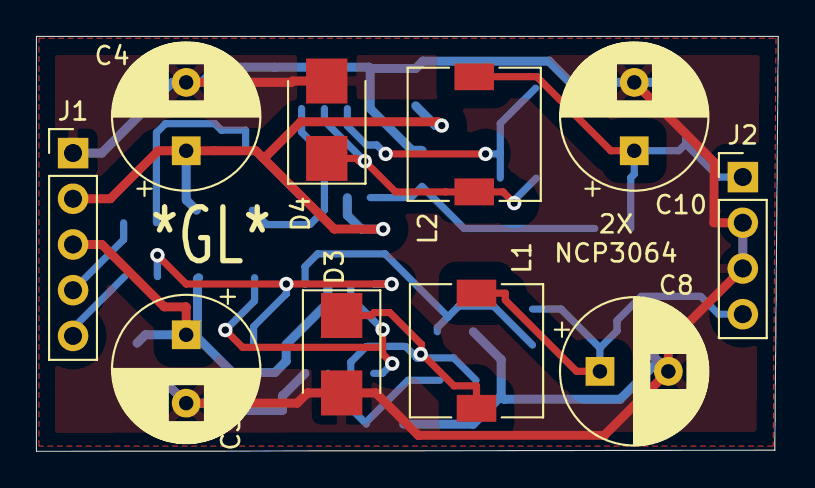
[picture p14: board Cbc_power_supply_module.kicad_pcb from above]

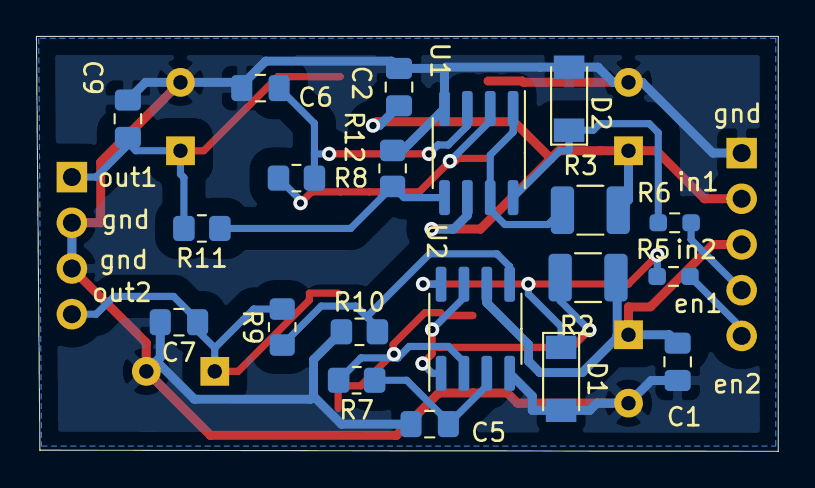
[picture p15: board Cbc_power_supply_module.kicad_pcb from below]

Board: 2 copper layers, 41.2 x 23.1 mm, 30 parts (20 on the bottom side), 17 nets.

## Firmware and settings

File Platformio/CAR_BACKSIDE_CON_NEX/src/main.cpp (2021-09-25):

#include <Arduino.h>
#include <avr/pgmspace.h>
#include "defines.h"
#include "init_functions.h"
#include "variables.h"

//libs
#include "EasyNextionLibrary.h"
#include <EEPROMex.h>
#include <EEPROMVar.h>
#include <OneWire.h>
#include <DallasTemperature.h>
#include "GyverHacks.h"
#include <GyverFilters.h>
#include <NonBlockingRtttl.h> // библиотека пиликалки
#include <GyverTimers.h>
#include <Arduino_FreeRTOS.h>
#include <ArduinoRS485.h>
#include <ArduinoModbus.h>
#include <timers.h>
#include "PJONSoftwareBitBang.h"
#include <queue.h>
#include <semphr.h>

PJONSoftwareBitBang bus;

#define TEMPERATURE_PRECISION 9                                  // точность измерения температуры 9 бит
OneWire oneWire(ONE_WIRE_PIN);                                   // порт шины 1WIRE
DallasTemperature temp_sensors(&oneWire);                        // привязка библиотеки DallasTemperature к библиотеке OneWire
DeviceAddress thermometerID_1, thermometerID_2, thermometerID_3; // резервируем адреса для трёх датчиков

GTimer timerPumpOffDelay; //
GTimer timerLowUConverterOffDelay;
GTimer timerConverterShutdownDelay;
GTimer timerPjonTransmittPeriod;
GTimer timerShutdownDelay;
GTimer timerMenuDynamicUpdate;
GTimer timerScreenOffDelay;
GTimer timerStartDelay;   // таймер задержки опроса входов после старта
GTimer timerPrxSensorFeedbackDelay;
GTimer timerSensSupplyCheck;
GTimer timerPjonFaultDetector;
GTimer timerFridgeShutdownDelay;

GFilterRA ps_voltage_filter;
GFilterRA sens_voltage_filter;
GFilterRA resistive_sensor_filter;

EasyNex myNex(Serial1);

//мелодии

const char *melody_1 = " melody1:d=4,o=7,b=1000:4c,4d,4e,4f,4g,4a,4h";
const char *melody_2 = " melody2:d=4,o=7,b=500:4c,4d,4e,4f,4g,4a,4h";
const char *melody_3 = " melody3:d=4,o=7,b=50:e";
const char *melody_4 = " melody4:d=4,o=5,b=160:1p,e6,8p,e6,8p,e6,8p"; // три длинных пика
const char *bip_1 = " Connect:d=4,o=6,b=2000:4g5,1p,2g";
const char *bip_2 = " Disconnect:d=4,o=6,b=2000:4g,1p,2g5";

// FreeRTOS functions
void TaskPilikalka(void *pvParameters);
void TaskLoop(void *pvParameters);
void TaskMenuUpdate(void *pvParameters);
void TaskTempSensorsUpdate(void *pvParameters);
void TaskPjonTransmitter(void *pvParameters);
void TaskVoltageMeasurement(void *pvParameters);
void TaskModBusPool(void *pvParameters);
void TaskOwScanner(void *pvParameters);
void TaskInputsUpdate(void *pvParameters);

#if (DEBUG_GENERAL)
void TaskDebug(void *pvParameters);
#endif

TaskHandle_t TaskPilikalka_Handler;
TaskHandle_t TaskLoop_Handler;
TaskHandle_t TaskMenuUpdate_Handler;
TaskHandle_t TaskTempSensorsUpdate_Handler;
TaskHandle_t TaskPjonTransmitt_Handler;
TaskHandle_t TaskVoltageMeasurement_Handler;
TaskHandle_t TaskModBusPool_Handler;
TaskHandle_t TaskOwScanner_Handler;
TaskHandle_t TaskInputsUpdate_Handler;
SemaphoreHandle_t OwScannerToStartSemaphore;
SemaphoreHandle_t SystemStartedSemaphore;
SemaphoreHandle_t AccessToMainDataMutex; // пока не используется
QueueHandle_t SendToPilikalkaQueue;

//functions
void fnMenuStaticDataUpdate(void);
void fnPumpControl(MyData &data);
void fnOutputsUpdate(MyData &data);  // функция обновления выходов
bool fnEEpromInit(void);             // функция загрузки уставок и проверка eeprom при старте
bool fnReadErrorLogFromEeprom(void); //
void fnConverterControl(MyData &data, Setpoints &setpoints);
void pj_receiver_function(uint8_t *payload, uint16_t length, const PJON_Packet_Info &packet_info);
void fnPjonSender(void);
void fnWaterLevelControl(MyData &data, PjonReceive &receive_data, Setpoints &setpoints, Alarms &alarms);
void fnMainPowerControl(MyData &data, Setpoints &setpoints, GTimer &timer);
uint8_t fnDebounce(uint8_t sample);
void fnSensorsSupplyControl(MyData &data, GTimer &timer, Alarms &alarms);
void fnResSensRead(MyData &data);
void fnAlarms(MyData &data, Alarms &alarms, Alarms &old_alarms, ErrLog &Log);



//обработчик прерывания от Timer3 (сброс внешнего WDT)
ISR(TIMER3_A)
{
      digitalWrite(WDT_RESET_OUT, !digitalRead(WDT_RESET_OUT));
}

//>>>>>>>>>>>>> SETUP >>>>>>>>>>>>>>>>>>>>>>>>>>>>>>>>>>>>>>>>>>>>>>>>>>>>>>>>>>>>>>>>>>>>>>>>>>>>>>>>>>>>>>>>>>>>>>>>>>>>>>>

void setup()
{

      Timer3.setPeriod(WDT_RESET_PERIOD); // Устанавливаем период таймера 500000 мкс -> 0.5 гц (сброс внешнего WDT)
      Timer3.enableISR(CHANNEL_A);

      fnIOInit();

      digitalWrite(MAIN_SUPPLY_OUT, HIGH);

#if (DEBUG_GENERAL)
      Serial.begin(115200);
#endif

      //меняем скорость Nextion (одноразово)
      /*
      Serial1.begin(9600); // нынешняя скорость / по умолчанию
      Serial1.print("bauds=115200"); // новая скорость
      Serial1.write(0xff);
      Serial1.write(0xff);
      Serial1.write(0xff); 
    */

      delay(2000);                    //задержка
      myNex.begin(NEXTION_BAUD_RATE); //
      myNex.writeStr("page 12");
      myNex.writeStr("page 12");
      myNex.writeStr("sleep=0");
      delay(500);
      //myNex.writeStr("dim=25");
      //myNex.writeStr("sleep=1");
      //delay(5000);
      //myNex.writeStr("sleep=0");

      if (fnEEpromInit())
      {
            myNex.writeStr("p12t0.txt", "Ok!");

            memcpy(&old_setpoints_data, &setpoints_data, sizeof(Setpoints)); // копирование структур с настройками для отслеживания изменений уставок

            // копирование адресов датчиков из структуры уставок которая сохранена в EEPROM
            memcpy(&thermometerID_1, &setpoints_data.sensors_ID_array[setpoints_data.sensors_select_array[INSIDE_SENSOR - 1] - 1][0], sizeof(thermometerID_1));  //
            memcpy(&thermometerID_2, &setpoints_data.sensors_ID_array[setpoints_data.sensors_select_array[OUTSIDE_SENSOR - 1] - 1][0], sizeof(thermometerID_2)); //
            memcpy(&thermometerID_3, &setpoints_data.sensors_ID_array[setpoints_data.sensors_select_array[SPARE_SENSOR - 1] - 1][0], sizeof(thermometerID_3));   //
      }
      else
      {
            myNex.writeStr("p12t0.txt", "fault!");
            while (1)
                  ;
      }

      delay(1500);

      ps_voltage_filter.setCoef(0.1); // установка коэффициента фильтрации (0.0... 1.0). Чем меньше, тем плавнее фильтр
      ps_voltage_filter.setStep(20);  // установка шага фильтрации (мс). Чем меньше, тем резче фильтр
      sens_voltage_filter.setCoef(0.1);
      sens_voltage_filter.setStep(50);
      resistive_sensor_filter.setCoef(0.02);
      resistive_sensor_filter.setStep(2000);

      temp_sensors.begin();
      temp_sensors.setResolution(thermometerID_1, TEMPERATURE_PRECISION);
      temp_sensors.setResolution(thermometerID_2, TEMPERATURE_PRECISION);
      temp_sensors.setResolution(thermometerID_3, TEMPERATURE_PRECISION);
      temp_sensors.setWaitForConversion(false);

      timerPumpOffDelay.setMode(MANUAL);
      timerLowUConverterOffDelay.setMode(MANUAL);
      timerLowUConverterOffDelay.setInterval(((uint32_t)setpoints_data.lowUconverter_off_delay) * MINUTE);
      timerConverterShutdownDelay.setMode(MANUAL);
      timerPjonTransmittPeriod.setInterval(setpoints_data.pjon_transmitt_period * MS_100);
      timerShutdownDelay.setMode(MANUAL);
      timerShutdownDelay.setInterval(setpoints_data.shutdown_delay * HOUR);
      timerScreenOffDelay.setMode(MANUAL);
      timerScreenOffDelay.setInterval(10000);
      timerMenuDynamicUpdate.setInterval(MENU_UPDATE_PERIOD);
      timerStartDelay.setMode(MANUAL);
      timerPrxSensorFeedbackDelay.setMode(MANUAL);
      timerPrxSensorFeedbackDelay.setInterval(PRX_SENSOR_FEEDBACK_DELAY);
      timerSensSupplyCheck.setMode(MANUAL);
      timerSensSupplyCheck.setInterval(SENS_SUPPLY_CHECK_START_DELAY);
      timerPjonFaultDetector.setMode(MANUAL);
      timerPjonFaultDetector.setInterval(setpoints_data.pjon_sensor_fault_timer * 1000);
      timerFridgeShutdownDelay.setMode(MANUAL); // пока не используется

      fnMenuStaticDataUpdate();

      bus.strategy.set_pin(PJON_BUS_PIN); // выбор пина дя передачи данных
      bus.set_id(setpoints_data.pjon_ID); //  установка собственного ID
      bus.begin();                        //
      bus.set_receiver(pj_receiver_function);

      ModbusRTUServer.begin(2, main_data.mb_rates[setpoints_data.mb_baud_rate]); // настройка порта в файле RS485.cpp в конце
      ModbusRTUServer.configureCoils(0x00, 10);
      ModbusRTUServer.configureHoldingRegisters(0x00, 10);

      timerConverterShutdownDelay.setInterval((setpoints_data.converter_shutdown_delay) * MINUTE);

      fnReadErrorLogFromEeprom();

      //********** FreeRTOS tasks ***************************************************
      xTaskCreate(
          TaskPilikalka, "Pilikalka" // A name just for humans
          ,
          100 // This stack size can be checked & adjusted by reading the Stack Highwater //72
          ,
          NULL, 2 // Priority, with 3 (configMAX_PRIORITIES - 1) being the highest, and 0 being the lowest.
          ,
          &TaskPilikalka_Handler);

      xTaskCreate(
          TaskLoop, "Loop" // A name just for humans
          ,
          192 // This stack size can be checked & adjusted by reading the Stack Highwater //192
          ,
          NULL, 1 // Priority, with 3 (configMAX_PRIORITIES - 1) being the highest, and 0 being the lowest.
          ,
          &TaskLoop_Handler);

      xTaskCreate(
          TaskMenuUpdate, "MenuUpdate" // A name just for humans
          ,
          192 // This stack size can be checked & adjusted by reading the Stack Highwater //192
          ,
          NULL, 2 // Priority, with 3 (configMAX_PRIORITIES - 1) being the highest, and 0 being the lowest.
          ,
          &TaskMenuUpdate_Handler);

      xTaskCreate(
          TaskTempSensorsUpdate, "TempSensorsUpdate" // A name just for humans
          ,
          192 // This stack size can be checked & adjusted by reading the Stack Highwater //128
          ,
          NULL, 3 // Priority, with 3 (configMAX_PRIORITIES - 1) being the highest, and 0 being the lowest.
          ,
          &TaskTempSensorsUpdate_Handler);

      xTaskCreate(
          TaskPjonTransmitter, "PjonTransmitt" // A name just for humans
          ,
          192 // This stack size can be checked & adjusted by reading the Stack Highwater // 128
          ,
          NULL, 3 // Priority, with 3 (configMAX_PRIORITIES - 1) being the highest, and 0 being the lowest.
          ,
          &TaskPjonTransmitt_Handler);

      xTaskCreate(
          TaskVoltageMeasurement, "VoltageMeasurement" // A name just for humans
          ,
          168 // This stack size can be checked & adjusted by reading the Stack Highwater //120
          ,
          NULL, 1 // Priority, with 3 (configMAX_PRIORITIES - 1) being the highest, and 0 being the lowest.
          ,
          &TaskVoltageMeasurement_Handler);

      xTaskCreate(
          TaskModBusPool, "ModBusPool" // A name just for humans
          ,
          700 // This stack size can be checked & adjusted by reading the Stack Highwater //690
          ,
          NULL, 2 // Priority, with 3 (configMAX_PRIORITIES - 1) being the highest, and 0 being the lowest.
          ,
          &TaskModBusPool_Handler);

      xTaskCreate(
          TaskOwScanner, "OwScanner" // A name just for humans
          ,
          192 // This stack size can be checked & adjusted by reading the Stack Highwater //128
          ,
          NULL, 3 // Priority, with 3 (configMAX_PRIORITIES - 1) being the highest, and 0 being the lowest.
          ,
          &TaskOwScanner_Handler);

      xTaskCreate(
          TaskInputsUpdate, "InputsUpdate" // A name just for humans
          ,
          192 // This stack size can be checked & adjusted by reading the Stack Highwater //128
          ,
          NULL, 3 // Priority, with 3 (configMAX_PRIORITIES - 1) being the highest, and 0 being the lowest.
          ,
          &TaskInputsUpdate_Handler);

      //**********************************************

      OwScannerToStartSemaphore = xSemaphoreCreateBinary();
      SystemStartedSemaphore = xSemaphoreCreateBinary();
      AccessToMainDataMutex = xSemaphoreCreateMutex();
      SendToPilikalkaQueue =  xQueueCreate(10, sizeof(uint8_t));

      //*********************************************

#if (DEBUG_GENERAL)
      xTaskCreate(TaskDebug,
                  "Serial",
                  210,
                  NULL,
                  1,
                  NULL);
#endif

      switch (setpoints_data.logo_selection)
      {
      case 0:
            myNex.writeStr("page 0");
            break;

      case 1:
            myNex.writeStr("page 13");
            break;

      case 2:
            myNex.writeStr("page 14");
            break;

      case 3:
            myNex.writeStr("page 15");
            break;

      default:
            break;
      }

      //rtttl :: begin (BUZZER, melody_2);   // пиликаем при старте
      timerStartDelay.setInterval(START_DELAY);
}

//>>>>>>>>>>>>>>>>>>>>>>>>>>>>>>>>>>>>>>>>>>>>>>>>>>>>>>>>>>>>>>>>>>>>>>>>>>>>>>>>>>>>>>>>>>>>>>>>>>>>>>>>>>>>>>>>>>>

void loop()
{

} //end loop

//>>>>>>>>>>>>>>>>>>>>>>>>>>>>>>>>>>>>>>>>>>>>>>>>>>>>>>>>>>>>>>>>>>>>>>>>>>>>>>>>>>>>>>>>>>>>>>>>>>>>>>>>>>>>>>>>>>>>>>

//menu static data update
void fnMenuStaticDataUpdate(void)
{
      switch (myNex.currentPageId)
      {

      case MAIN_PAGE:

            break;

      case WATER_PAGE:

            break;

      case IOSTATUS_PAGE:

            break;

      case SETTINGS_PAGE:

            break;

      case ONEWIRESET_PAGE:
            //обновляем статические параметры страницы

            for (uint8_t j = 0; j < 8; j++)
            {
                  tempString2 = String(setpoints_data.sensors_ID_array[0][j], HEX);
                  tempString += tempString2;
                  if (j < 7)
                        tempString += ". ";
            }

            myNex.writeStr("p4t2.txt", tempString);
            tempString = "";
            tempString2 = "";

            for (uint8_t j = 0; j < 8; j++)
            {
                  tempString2 = String(setpoints_data.sensors_ID_array[1][j], HEX);
                  tempString += tempString2;
                  if (j < 7)
                        tempString += ". ";
            }

            myNex.writeStr("p4t3.txt", tempString);
            tempString = "";
            tempString2 = "";

            for (uint8_t j = 0; j < 8; j++)
            {
                  tempString2 = String(setpoints_data.sensors_ID_array[2][j], HEX);
                  tempString += tempString2;
                  if (j < 7)
                        tempString += ". ";
            }

            myNex.writeStr("p4t11.txt", tempString);
            tempString = "";
            tempString2 = "";

            break;

      case WATERSET_PAGE:

            break;

      case CONVSET_PAGE:

            break;

      case LIGHTSET_PAGE:

            break;

      case PJONSET_PAGE:

            break;

      case ONEWIRESCANNER_PAGE:

            break;

      case MODBUSSET_PAGE:

            break;

      case BASESET_PAGE:

            break;

      default:
            break;
      }
}
//*********************************************************************************

// trigger1 определение текущей страницы (не используется)
void trigger1()
{
      //current_page = myNex.readNumber("dp");
      //current_page = myNex.readNumber("dp");
}
//*********************************************************************************

//trigger2 инкремент уставок
void trigger2()
{
      *variable_value = *variable_value + 1;
      if (*variable_value > var_max_value)
            *variable_value = var_min_value;
      flag_value_changed = HIGH;
}
//*********************************************************************************

//trigger3 декремент уставок
void trigger3()
{
      *variable_value = *variable_value - 1;
      if (*variable_value < var_min_value)
            *variable_value = var_max_value;
      flag_value_changed = HIGH;
}
//**********************************************************************************

//trigger4 кнопка ENTER (сохранение уставок в EEPROM )
void trigger4()
{
      taskENTER_CRITICAL();
      EEPROM.updateBlock(EEPROM_SETPOINTS_ADDRESS, setpoints_data);
      memcpy(&old_setpoints_data, &setpoints_data, sizeof(Setpoints));
      taskEXIT_CRITICAL();
      timerPjonTransmittPeriod.setInterval(setpoints_data.pjon_transmitt_period * MS_100); // обновление интервала
      flag_value_changed = LOW;
}
//**********************************************************************************

// trigger 5 определяет текущий пункт меню на странице настроек
void trigger5()
{
      current_item = myNex.readNumber("currentItem.val");
      current_item = myNex.readNumber("currentItem.val");
}
//**********************************************************************************

// trigger 6 ручное включение насоса
void trigger6()
{
      current_item = myNex.readNumber("currentItem.val");
      current_item = myNex.readNumber("currentItem.val");
      main_data.pump_output_state = 1 - main_data.pump_output_state;
      if (main_data.pump_output_state)
            timerPumpOffDelay.setInterval(setpoints_data.pump_off_delay * SECOND);
      else
            timerPumpOffDelay.stop();
}
//**********************************************************************************

// trigger 7 сканнер 1Wire (перенесен в задачу)
void trigger7()
{
      //flag_ow_scan_to_start = TRUE;
      xSemaphoreGive(OwScannerToStartSemaphore);
}
//*******************************************************************************

// trigger 8 flow sensor reset
void trigger8()
{

      if (!bus.update())
      {
            bus.send_packet(PJON_WATER_FLOW_SENSOR_ID, "RESET", 5); //отправляем команду сброса счетчику воды
      }
}
//******************************************************************************

// trigger 9  Error log reset
void trigger9()
{
      taskENTER_CRITICAL();
      memset(&ErrorLog, 0, sizeof(ErrorLog));
      EEPROM.updateBlock(EEPROM_ERROR_LOG_ADDRES, ErrorLog);
      taskEXIT_CRITICAL();
      main_data.common_alarm = false;
}
//******************************************************************************

// trigger 10  Sens supply error  reset
void trigger10()
{
      present_alarms.sens_supply = false;
}
//******************************************************************************

//pump control
void fnPumpControl(MyData &data)
{

      uint8_t melody_ID = 0;
      if (data.door_switch_state)
      {
            if ((data.proximity_sensor_state == HIGH) && (proximity_sensor_old_state == LOW) && (timerPrxSensorFeedbackDelay.isReady()))
            {
                  data.pump_output_state = 1 - data.pump_output_state;
                  timerPrxSensorFeedbackDelay.setInterval(PRX_SENSOR_FEEDBACK_DELAY);
                  melody_ID = 1;
                  xQueueSend(SendToPilikalkaQueue, &melody_ID, 0);
                  if (data.pump_output_state)
                        timerPumpOffDelay.setInterval(setpoints_data.pump_off_delay * SECOND);
                  else
                        timerPumpOffDelay.stop();
            }
      }
      else
      {
            data.pump_output_state = LOW;
            timerPumpOffDelay.stop();
      }

      proximity_sensor_old_state = data.proximity_sensor_state;

      if (timerPumpOffDelay.isReady())
      {
            data.pump_output_state = LOW;
            timerPumpOffDelay.stop();
      }
}
//*******************************************************************************

//Outputs Update
void fnOutputsUpdate(MyData &data)
{ // функция обновления состояния выходов

     // if (xSemaphoreTake(AccessToMainDataMutex, 10) == pdTRUE){
            digitalWrite(WATER_PUMP_OUTPUT_1, data.pump_output_state); //
            digitalWrite(LIGHT_OUTPUT_2, data.light_output_state);     //
            digitalWrite(CONVERTER_OUTPUT_3, data.converter_output_state);
            digitalWrite(SENSORS_SUPPLY_5v, data.sensors_supply_output_state);
            digitalWrite(MAIN_SUPPLY_OUT, data.main_supply_output_state);
     // }

     // xSemaphoreGive(AccessToMainDataMutex);
}
//*******************************************************************************

//EEPROM Init
bool fnEEpromInit(void)
{

      EEPROM.readBlock(EEPROM_SETPOINTS_ADDRESS, setpoints_data); // считываем уставки из eeprom
      if (setpoints_data.magic_key == MAGIC_KEY)
      {                  // если ключ совпадает значит не первый запуск
                         // digitalWrite(BUILTIN_LED, HIGH); // и зажигаем светодиод для индикации
            return true; // возвращаем один
      }
      else // если ключ  не совпадает значит первый запуск
      {
            myNex.writeStr("p12t0.txt", "Writing defaults...");
            for (uint8_t i = 0; i < 3; i++)
            { // мигнём три раза
                //  digitalWrite(BUILTIN_LED, HIGH);
                //  delay(1000);
                //  digitalWrite(BUILTIN_LED, LOW);
                //  delay(1000);
            }

            fnDefaultSetpointsInit();                                    // присвеиваем уставки по умолчанию
            EEPROM.writeBlock(EEPROM_SETPOINTS_ADDRESS, setpoints_data); // и записываем
            EEPROM.readBlock(EEPROM_SETPOINTS_ADDRESS, setpoints_data);  // считываем уставки из eeprom

            if (setpoints_data.magic_key == MAGIC_KEY)
            { // проверяем ключ ещё раз
                 // digitalWrite(BUILTIN_LED, HIGH);
                  return true;
            }
            else // если не совпадает значит проблемы с EEPROM
            {
                 // digitalWrite(BUILTIN_LED, LOW);
                  return false; // возвращаем ноль
            }
      }
}
//*******************************************************************************
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

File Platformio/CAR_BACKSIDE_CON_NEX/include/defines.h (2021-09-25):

#ifndef DEFINES_H
#define DEFINES_H

#include <Arduino.h>

#define DEBUG_GENERAL   1
#define DEBUG_RTOS      0
#define DEBUG_ERROR_LOG 0

//colors
#define WHITE       65535
#define YELLOW      65504
#define BLUE        20510
#define GREEN       33792
#define GRAY        27469
#define GRAY2       50712
#define RED         57543
#define BLUE_2         31
#define CYAN         2831
#define UNSAVED_ITEM_COLOR  YELLOW


//timers
#define TEMP_SENSORS_UPDATE_PERIOD   1000   //ms
#define MENU_UPDATE_PERIOD           500    //ms
#define SENS_SUPPLY_CHECK_PERIOD     100    //ms
#define SENS_SUPPLY_CHECK_TIMES      5
#define SENS_SUPPLY_CHECK_MIN_V      4
#define SENS_SUPPLY_CHECK_START_DELAY 2000  //ms  

#define NEXTION_BAUD_RATE            115200

//menu pages
#define MAIN_PAGE              0
#define WATER_PAGE             1
#define IOSTATUS_PAGE          2
#define SETTINGS_PAGE          3
#define ONEWIRESET_PAGE        4
#define WATERSET_PAGE          5
#define CONVSET_PAGE           6
#define LIGHTSET_PAGE          7
#define PJONSET_PAGE           8
#define ONEWIRESCANNER_PAGE    9
#define MODBUSSET_PAGE        10
#define BASESET_PAGE          11
//#define INIT_PAGE             12
//#define LOGO_0_PAGE           13
//#define LOGO_1_PAGE           14
//#define LOGO_2_PAGE           15
#define ERROR_LOG_PAGE        0X10
#define TIMERS_PAGE           0x11
#define MAX_PAGES             20 

//modes
#define OFF_MODE               0
#define ON_MODE                1
#define AUTO_MODE              2

//water sensors types
#define WATER_FLOAT_SENSOR_PJ  0
#define WATER_FLOW_SENSOR_PJ   1
#define WATER_RESISTIVE_SENSOR 2

//resistive sensor nominal
#define MIN_RESISTANCE          10
#define MAX_RESISTANCE          255

//eeprom
#define EEPROM_SETPOINTS_ADDRESS   0
#define EEPROM_ERROR_LOG_ADDRES    100
#define MAGIC_KEY                  0xAC   // 0xAB ключь для определения записаны ли уставки в память EEPROM
//#define MAGIC_KEY_PART_1          0x1234567   // вариант с двумя частями один в начале второй в конце
//#define MAGIC_KEY_PART_2          0x7654321

//communications
#define PJON_BUS_PIN         3   // new 
#define ONE_WIRE_PIN         4
#define DE_RS485_PIN         6   // in RS485.h

// water level sensor
#define WATER_LEVEL_LESS_THEN_25      1      
#define WATER_LEVEL_25                2
#define WATER_LEVEL_50                3
#define WATER_LEVEL_75                4
#define WATER_LEVEL_100               5
#define WATER_LEVEL_SENSOR_DEFECTIVE  6

// onewire
#define MAX_TEMP_SENSORS        3
#define INSIDE_SENSOR           1
#define OUTSIDE_SENSOR          2
#define SPARE_SENSOR            3

//inputs
#define DOOR_SWITCH_INPUT_1                 54       //A0
#define PROXIMITY_SENSOR_INPUT_2            55       //A1
#define IGNITION_SWITCH_INPUT_3             56       //A2 
#define LOW_WASHER_WATER_LEVEL_INPUT_4      57       //A3
#define SUPPLY_VOLTAGE_INPUT                A4       //A4
#define SENSORS_VOLTAGE_INPUT               A5       //A5
#define RESISTIVE_SENSOR                    A6       //A6
#define WATER_FLOW_SENSOR                    5       //YF-S201 (пока не используется)
#define BUTTON_ON_BOARD                     10       // кнопка на плате (пока не используется)
#define POWER_OK_FROM_ADM705                41       //
//#define ENCODER_SW							35
//#define ENCODER_DT							36
//#define ENCODER_CLK							37


//outputs
#define WATER_PUMP_OUTPUT_1      22  
#define LIGHT_OUTPUT_2           23  
#define CONVERTER_OUTPUT_3       24  
#define SENSORS_SUPPLY_5v         7  
#define MAIN_SUPPLY_OUT			  9 
#define BUZZER                    2  
#define BUILTIN_LED              13
#define WDT_RESET_OUT             8  

//pjon swbb
#define PJON_MY_ID                    2
#define PJON_MAIN_CONTROLLER_ID       1
#define PJON_WATER_FLOAT_SENSOR_ID    3
#define PJON_WATER_FLOW_SENSOR_ID     4
#define PJON_MAX_NODES                2 // пока два


#define VERSION "ver 1.0"
#define DIVISION_RATIO_VOLTAGE_INPUT      0.0208      // разрешение 0.0025 уможить на коэфициент деления предусилителя 4.85(или делителя)
#define DIVISION_RATIO_SENS_SUPPLY_INPUT  0.0106      // разрешение 0.0025(для TL431) или 0.00256 (для внутреннего опорного 2.56в) уможить на коэфициент деления предусилителя 4.16
#define DIVISION_RATIO_RESIST_SENSOR      0.29       //0.278       //

#define MS_100        100           //  100ms
#define SECOND       1000           //ms  секунда
#define MINUTE       60000          //ms  минута
#define HOUR         3600000        //ms  час


#define START_DELAY                 3000  //ms задержка выполнения некоторых функций после подачи питания (пока датчики запустятся)
#define PRX_SENSOR_FEEDBACK_DELAY   500   //ms задержка реакции датчика приближения (для стабильности)
#define WDT_RESET_PERIOD        500000  // us период сброса ADM705 < 1.6 sec

#endif

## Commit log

2020-12-25 оптимизация, перенос строк во флэш
2021-01-08 добавлен антидребезг на основе вертикальных счетчиков
2021-01-29 Added PCB
    [Analog_input.sch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]
2021-03-26 Sensors supply control
    added sensors supply control function +
    pin DE control
2021-03-27 Resistive sensor
    Added analog read resestive sensor resistance function
2021-04-20 big update
    [Analog_input.sch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]
2021-04-22 update pcb
    [Analog_input.sch, Car_bs_controller_nex_mega.kicad_pcb]
2021-05-08 Pcb and shematic changed
    [CBC_pinout.xlsx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]
2021-05-17 wiring diagram and program changes
    [Analog_input.sch, Car_bs_controller_nex_mega.sch, Digital_inputs.sch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]
2021-05-17 wiring diagram changes
    [Links.sch]
2021-06-28 Added timers screen
